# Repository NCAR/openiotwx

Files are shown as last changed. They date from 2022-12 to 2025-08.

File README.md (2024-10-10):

# openIoTwx

Repo hosting the openIoTwx project by NCAR.

This website is currently a work in progress and is live here:

* [https://ncar.github.io/openiotwx](https://ncar.github.io/openiotwx)

If you are looking for the overarching openIoTwx Github repository (aka "openIoTwx Hub"), please go here:

* openIoTwx Hub repository: [https://github.com/ncar/openiotwx-hub](https://github.com/ncar/openiotwx-hub)

# For Developers 

We welcome contributions, so if you wish to contribute to this project please understand how to build it first.

The main development site uses [Material for MkDocs](https://squidfunk.github.io/mkdocs-material/).  You can [learn how to install it](https://squidfunk.github.io/mkdocs-material/getting-started/) and then you will be able to begin contributing.

The best way to work on this is to:

* fork the repo
* make a branch to work on revisions
* test locally using `mkdocs serve` (you will need to install mkdocs according to the documentation) 
* submit a Pull Request

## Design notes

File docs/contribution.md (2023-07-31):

# Contributing to this Project

We welcome any and all contributions. We'd love not only to see pictures of your builds and the data
that you produce (if you're willing to share), but also support for new sensors, new 3d designs for 
parts, and any feedback you have.

This [google form](https://forms.gle/mJmh5QLR8TvUpvbg8) is the best way to contribute non-code items. 

If you want to look further into this project, visit our various github repositories.

* For general issues and contributions go [here](https://github.com/NCAR/openiotwx-hub)
* For print issues and contribution go [here](https://github.com/NCAR/openiotwx-stl)
* For suggestions about this site go [here](https://github.com/NCAR/openiotwx)
* For issues and contributions to the flash code go [here](https://github.com/NCAR/esp32-atomlite-arduino-base)
* For issues and contributions to the library code go [here](https://github.com/NCAR/esp32-atomlite-arduino-iotwx)

Pieces we would love for you to contribute:

* A housing and sensor system for measuring atmospheric pollutants
* A low cost and low complexity method for getting anemometry
* Water quality / PFAS sensor integration

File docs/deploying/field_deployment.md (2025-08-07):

Properly situating a weather station in the field requires careful consideration for accurate data collection. When selecting a location, keep in mind a few important factors. 

* Place the weather station away from obstacles like tall trees or buildings that can disrupt airflow and affect wind measurements.
* Avoid areas with artificial heat sources such as asphalt or concrete, as they can cause higher temperature readings. 
* Also, make sure to position the station on stable ground to prevent measurement errors and ensure equipment stability.
* Mount the station at a suitable height, typically 1.5 to 2 meters above the ground, for reliable data.
* For LoRA Gateway Deployment, mount gateways at structural or geographic high point to maximize line of sight distance (i.e. roof, attic window, hilltop)
* For LoRA deployments, review antenna specifications for orientation to maximize signal. 

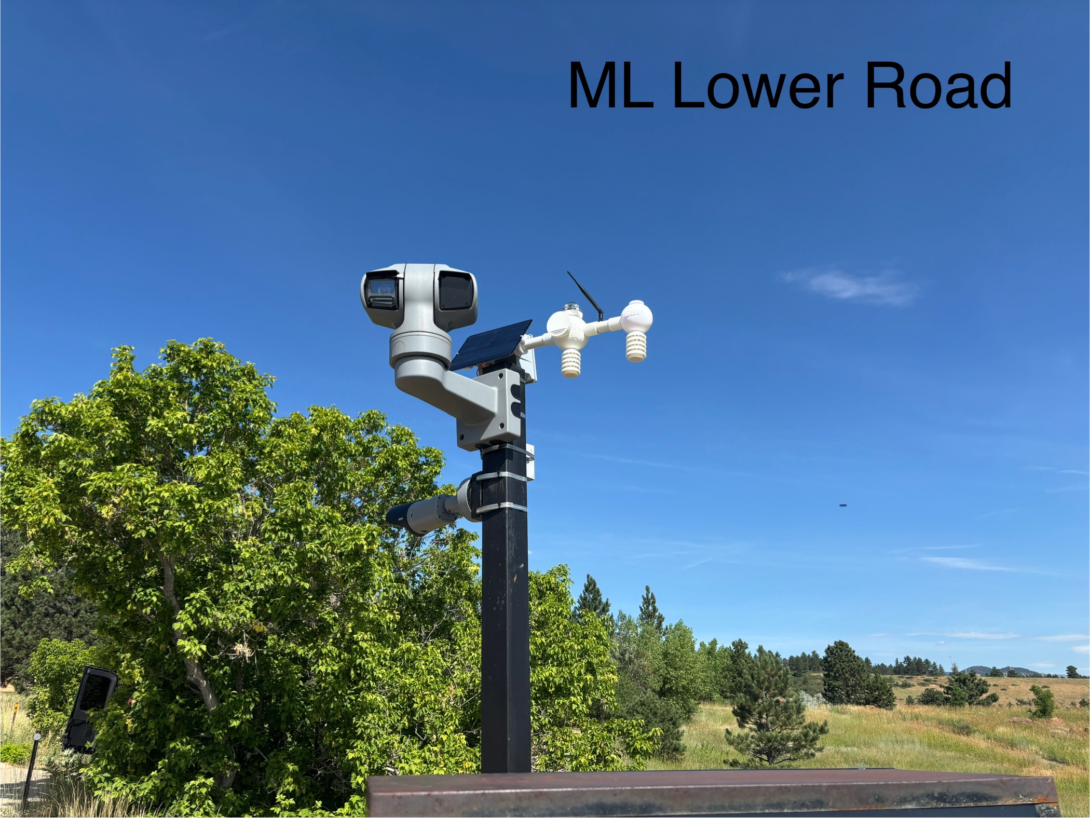
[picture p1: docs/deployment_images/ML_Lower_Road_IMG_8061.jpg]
Deployment ML Lower Road

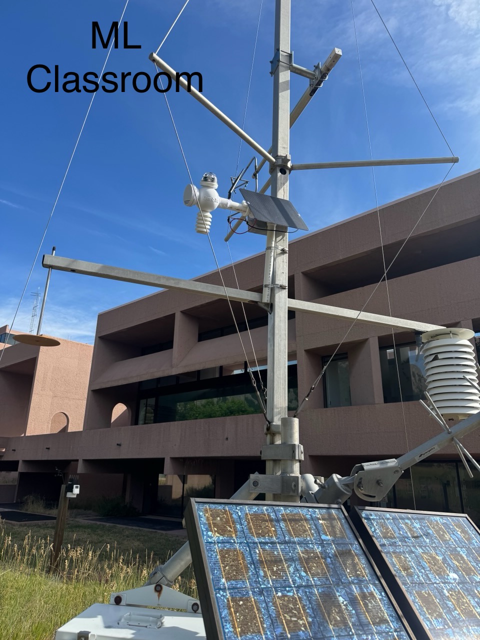
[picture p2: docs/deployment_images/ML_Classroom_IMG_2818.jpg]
Deployment ML Classroom

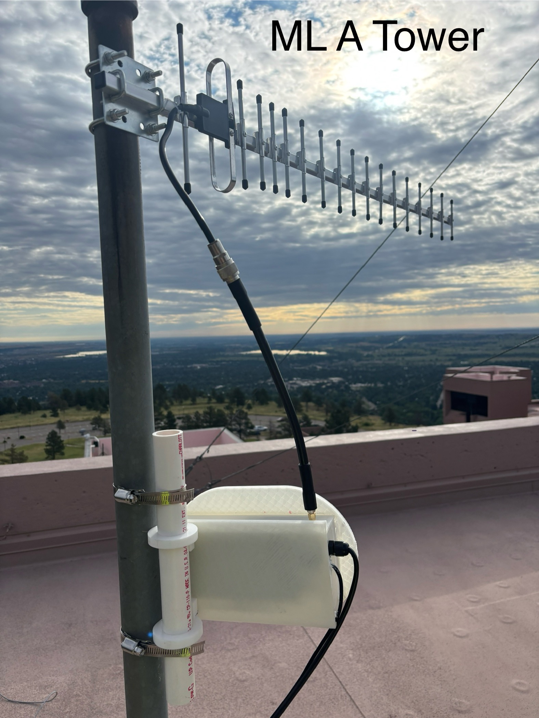
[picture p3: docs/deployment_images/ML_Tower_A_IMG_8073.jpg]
Deployment ML Tower A1 Gateway

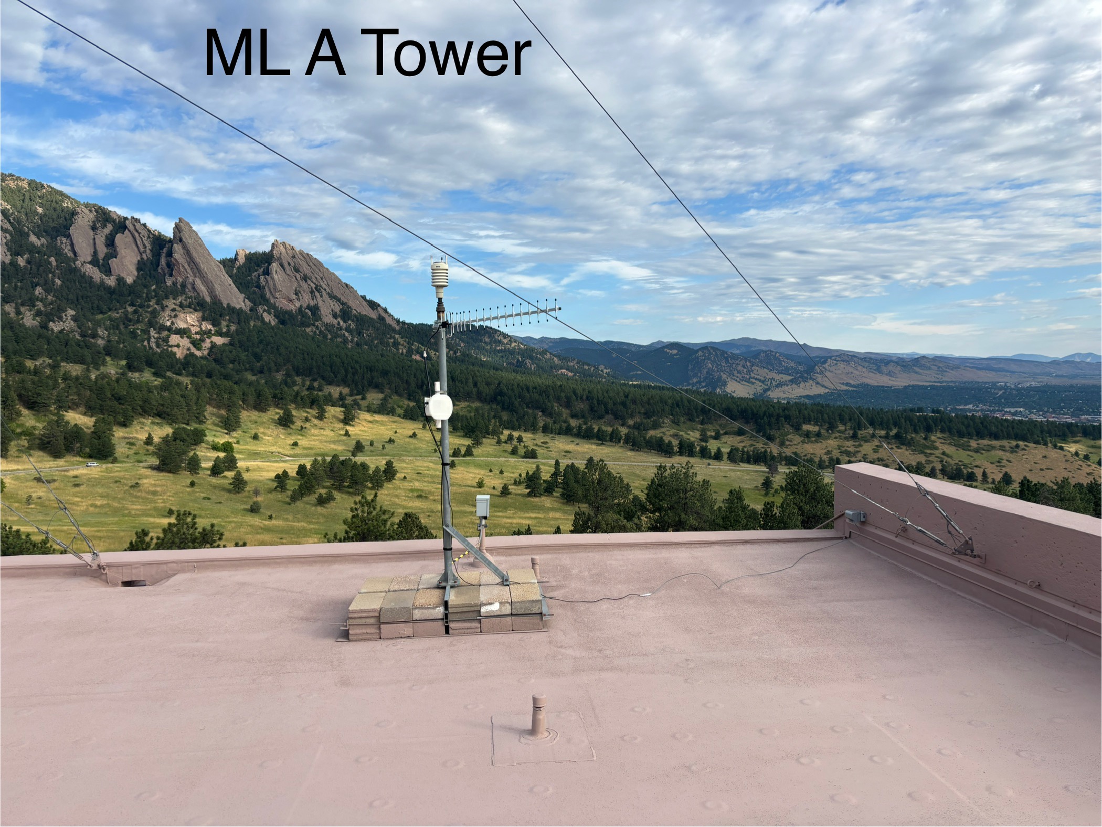
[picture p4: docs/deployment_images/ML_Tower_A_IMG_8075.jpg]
Deployment ML Tower A2 Gateway

Deployment ML Tower B Gateway
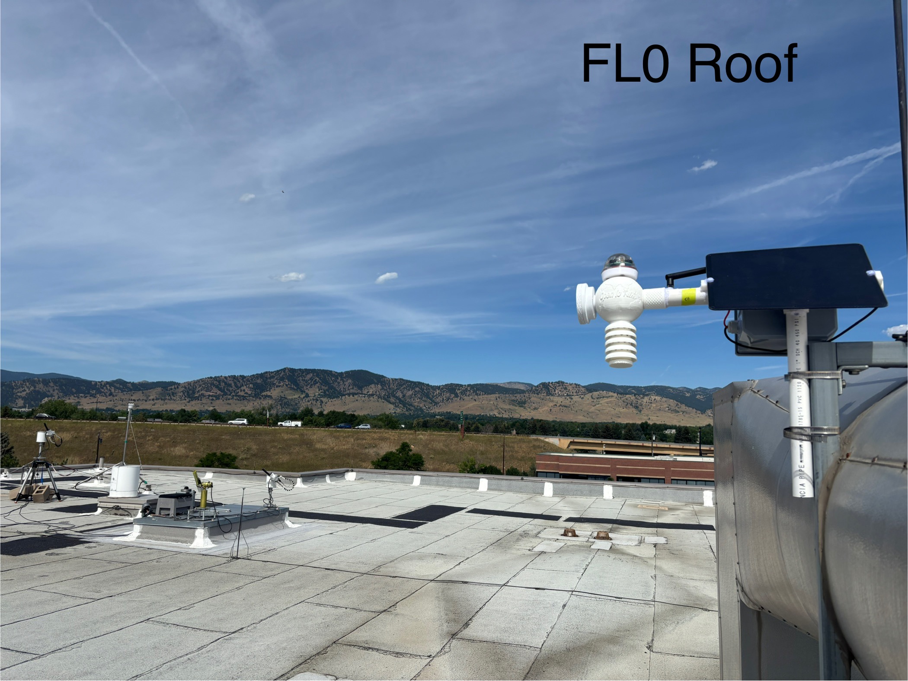
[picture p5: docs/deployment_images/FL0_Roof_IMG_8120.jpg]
Deployment FL Roof Gateway

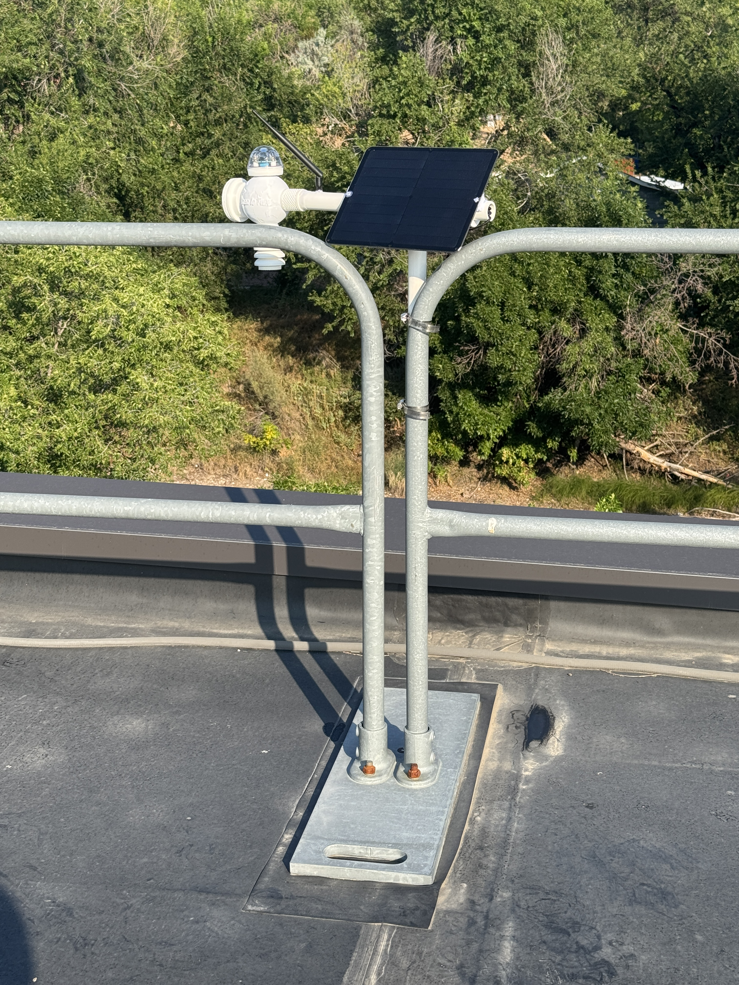
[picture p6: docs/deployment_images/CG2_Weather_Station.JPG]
Deployment CG2 Station

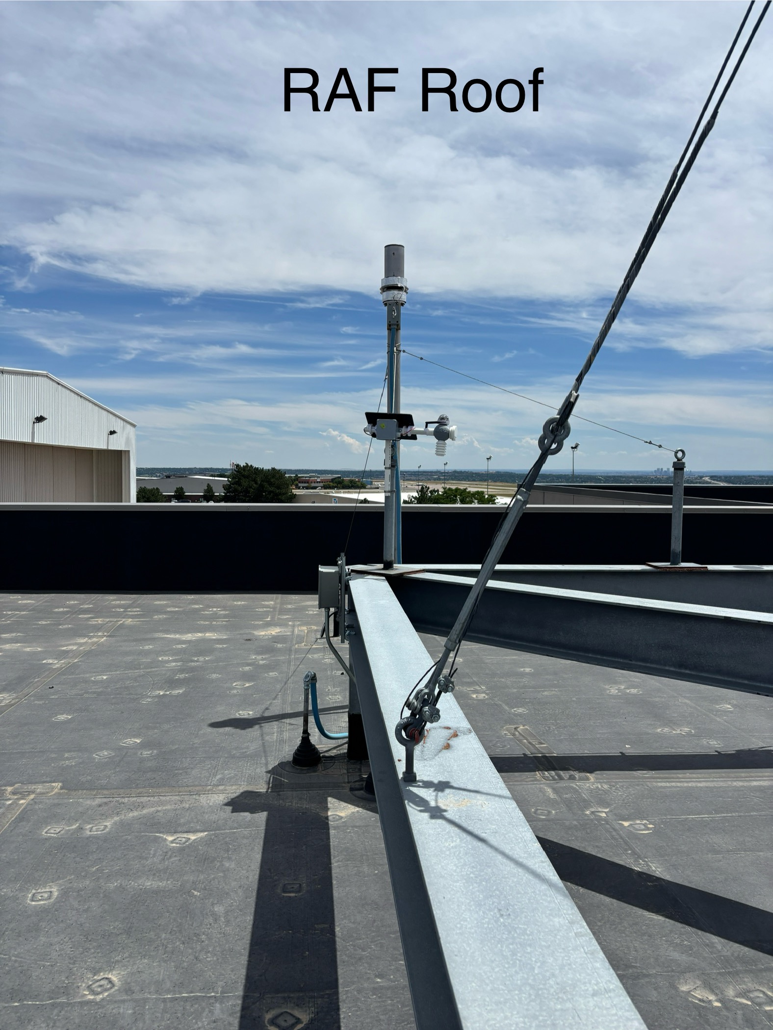
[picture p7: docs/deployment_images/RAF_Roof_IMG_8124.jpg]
Deployment RAF Station

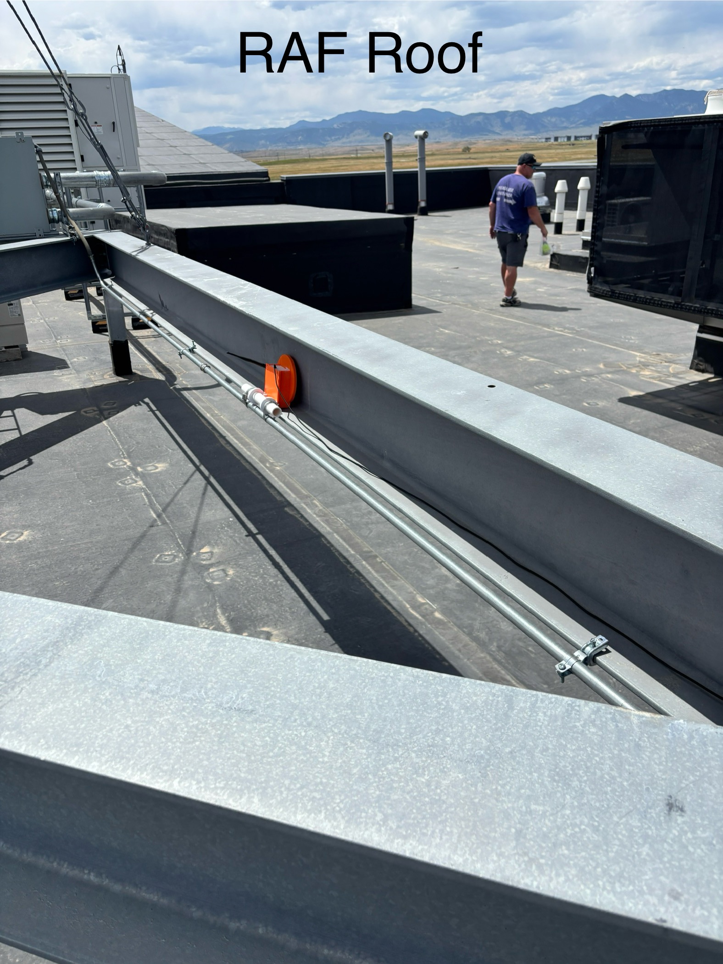
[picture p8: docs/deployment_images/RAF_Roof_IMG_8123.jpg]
Deployment RAF Roof Gateway

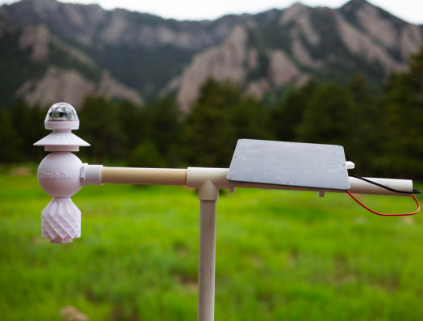
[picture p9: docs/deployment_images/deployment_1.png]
Deployment Example 1

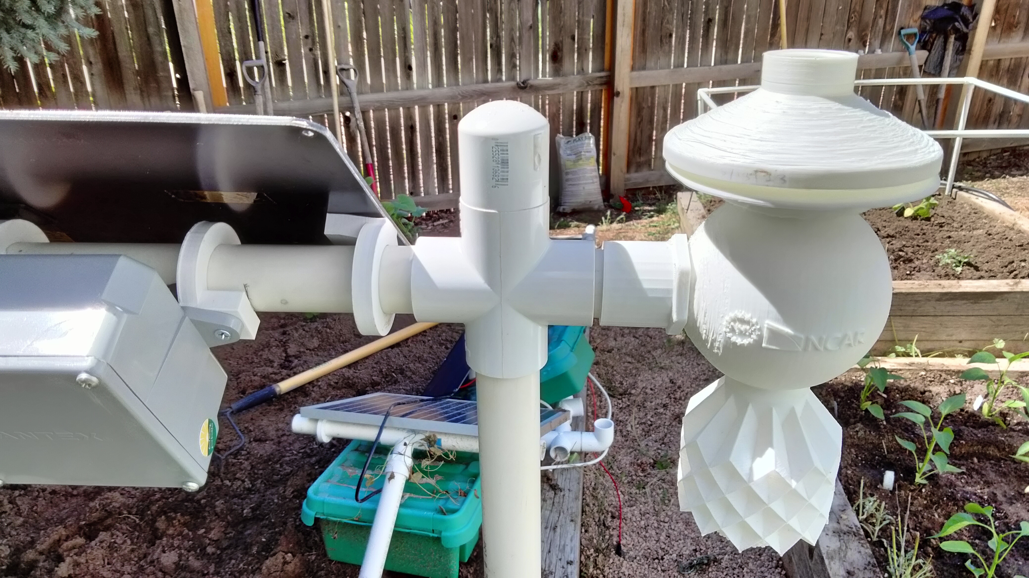
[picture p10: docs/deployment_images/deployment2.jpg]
Deployment Example 2


<!-- jfslhohshofsd -->

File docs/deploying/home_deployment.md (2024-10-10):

When deploying a weather station at a home, school, or in an otherwise developed area, there are a few important considerations to keep in mind. 

* Choose a location that is free from immediate obstructions such as nearby trees or tall structures that could affect other weather measurements. 
* Mount the station at a suitable height, typically 1.5 to 2 meters above the ground, for reliable data.
* Ensure that the station is not in direct contact with the building or any heat-emitting sources that could impact temperature readings.
* It is recommended to position the weather station in an area that receives adequate sunlight and is representative of the general microclimate of your surroundings. Avoid placing the station in shaded areas or near reflective surfaces that could distort solar radiation measurements. 
* Additionally, make sure the station is securely mounted, taking into account factors like stability and ease of access for maintenance.
* Regular checks and comparisons with nearby official weather sources can help ensure the accuracy of the collected data.

Deployment Example 1

Deployment Example 2

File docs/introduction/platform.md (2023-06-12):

# Platform

openIoTwx is an open source community committed to increasing access to weather
observation hardware, software, and data. This is achieved through our portable, 
modular, and affordable platform. openIoTwx can be installed with up to 7 
sensors or "nodes." These nodes include, but are not limited to: temperature, relative 
humidity, pressure, volatile organic compounds (VOCs), digital rain sensors, sky 
cameras, and sonic anemometers (Devices that measure wind speed). The platform is 
small enough to mount anywhere using low cost commercial off-the-shelf materials and 
3D printed parts.

Any of these nodes can be attached to the body using universal one inch screw-in 
connectors. This approach allows for any 1" PVC pipe or other threaded connector to be 
used as a base for the station. This specification was chosen due to how commonly 
available it is to find components that fit. The body of the station has threaded 
connectors. Depending on the housing used, there are between three and five ports. 

Users are provided with a starter set of screw in adaptors for an initial 
set of sensors such as the RG15 digital rain sensor, 
air quality monitor, and radiation shields. We also provide screw-in connectors with a 
cap so that users can cap off connectors not in use and deploy. This prevents water and 
dust from getting into the electronics. Should a user want to attach a new sensor, they 
can modify the 3D design files (provided in the print section) for whatever their 
needs demand.

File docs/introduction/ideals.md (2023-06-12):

# Ideals
The "Internet of Things" (IoT) revolution is about the world of sensors,
software, and electronics. It allows for ubiquitous, low-cost, and high quality
measurements of many things, including our Earth system. Due to low
cost-barriers, these sensing systems are now broadly accessible to many
communities. We hope that openIoTwx can continue piquing new interest in measurements and data relating to the all
aspects of our environment around us. We advise all members of our community to
review and regularly reflect on the core ideals outlined here.

The goals and core ideals of the openIoTwx project is _to advance low cost IoT
based geoscience observational projects_ via four objectives that align with and
build upon the National Science Foundation's (NSF) investments in the EarthCube
Community, ACCESS/Jetstream, 3D printed weather stations (aka "openIoTWx") and
future needs:

(1) create an open, diverse, community-driven and community-managed ecosystem to
empower fledgling open source sensor projects for open environmental sensing.

(2) implement an efficient, scalable, and simplified open project submission and
contribution framework to provide equitable access across disciplines,
stakeholders, institutions, and demographics to grow a community managed suite
of open source IoT observational sensor network projects;

(3) building upon NSF’s Cloud-Hosted Real-time Data Services for the Geosciences
(CHORDS) and other components, develop a robust, decentralized, and flexible
community software contribution platform to bring the open source project
development and design cycle into a new collaborative and cooperative
environment to spur sustainable community growth; 

(4) provide cyber-infrastructure (CI) integration through the ACCESS innovation
pilot program to manage dataflows, analysis, address artificial intelligence and
machine learning of earth science time series streams, creating open source
community deployments that are accessible while recognizing and honoring data
sovereignty aspects of our communities.

## Opensource is at our core
Our community holds the ideals of open source technology very close (for more
see [https://opensource.org](https://opensource.org)). openIoTwx broadly
promotes the MIT open source license and is accessible to all for non-commercial
use. Open source is an important ideal for our community because it facilitates
community engagement, provides transparency that builds trust and encourages
sharing of data, code, hardware  community earth system science data and ideas.

## FAIR and CARE 
We are committed to the Findability, Accessibility, Interoperability, and Reuse
(FAIR) of all digital assets (see
[https://www.go-fair.org/fair-principles/](https://www.go-fair.org/fair-principles/))
needed to design, modify, build, deploy, analyze and archive the openIoTwx
station. The FAIR principle as defined by GO-FAIR.ORG is a core value that will
help make this community open and accessible to all.

We balance adherence to FAIR principles with CARE
([https://www.gida-global.org/care](https://www.gida-global.org/care)) or
Collective Benefit, Authority to Control, Responsibility, and Ethics. This is
important for our community members from tribal communities and
other marginalized groups. Please review the CARE principle
summary as linked above.

## FPIC 
Free Prior and Informed Consent (FPIC) is a specific right that pertains to
indigenous peoples and is recognised in the United Nations Declaration on the
Rights of Indigenous Peoples (UNDRIP). It allows them to give or withhold
consent to a project that may affect them or their territories. This is another
core ideal of the openIoTwx community and should also be reviewed. (for
more see [https://www.fao.org/indigenous-peoples/our-pillars/fpic/en/](https://www.fao.org/indigenous-peoples/our-pillars/fpic/en/))

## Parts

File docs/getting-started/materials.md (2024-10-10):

# Materials

Within this page you can see all of the required materials for building the base unit, as 
well as the materials for adding sensors and other 'accessory' nodes. If you already have some of 
these pieces, for example, a 3d printer, you don't need to factor that into the cost. We have 
included every sensor that we currently support for the station within this list. If you have other 
sensors you wish to include, we would be thrilled for you to modify the codebase and send us a pull request 
or send a comment to us via our [Contribution](../contribution.md) portal.

The station can be powered and connected via ethernet or independently. The materials needed will be different depending on which configuration you use. Pay attention to the headings on the table below to make sure the materials you purchase are appropriate for the configuration that meets your needs. If you need more information to decide which configuration is best for your specific circumstance, go to the [Determining power & internet needs](../getting-started/connection.md) page.

## Printing Gear

Only one roll of filament is required.

|Area|Component|Price Per Unit|Number of Units|Total Price|Source|
|---|---|---|---|---|---|
|Printing|Ender 3 S1|$349.00|1|$349.00|[(Amazon)](https://www.amazon.com/Creality-S1-Extruder-Mainboard-8-6X8-6X10-6in/dp/B07DYL9B2S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)|
|Printing|PLA+ Filament|$20.99|1|$20.99|[(Amazon)](https://www.amazon.com/Printer-Filament-SUNLU-Dimensional-Accuracy/dp/B08CVG79JM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)|
|Printing|Tough PLA|$24.99|1|$24.99|[(Amazon)](https://www.amazon.com/Inland-Tough-Printer-Filament-1-75/dp/B09P497QP7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)|

## Base Station with Independent Comms and Power

|Area|Component|Price Per Unit|Number of Units|Total Price|Source|
|---|---|---|---|---|---|
|Microcontroller|M5 atomlite|$7.50|1|$7.50|[(M5)](https://shop.m5stack.com/products/atom-lite-esp32-development-kit)|
|Cables|qwiic to grove cable|$1.60|1|$1.60|[(sparkfun)](https://www.sparkfun.com/products/15109)|
|Cables|qwiic adapter|$1.60|1|$1.60|[(sparkfun)](https://www.sparkfun.com/products/14495)|
|Cables|qwiic multiport|$2.10|1|$2.10|[(sparkfun)](https://www.sparkfun.com/products/18012)|
|Cables|qwiic cable 500mm|$2.10|1|$2.10|[(sparkfun)](https://www.sparkfun.com/products/17257)|
|Cables|qwiic cable 200mm|$1.60|2|$3.20|[(sparkfun)](https://www.sparkfun.com/products/17258)|
|Cables|qwiic cable 100mm|$1.60|1|$1.60|[(sparkfun)](https://www.sparkfun.com/products/17259)|
|Cables|Grove to GPIO|$3.50|1|$3.50|[(Seeed studio)](https://www.seeedstudio.com/Grove-4-pin-Female-Jumper-to-Grove-4-pin-Conversion-Cable-5-PCs-per-PAck.html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)|
|Cables|Qwiic to GPIO|$1.50|1|$1.50|[(sparkfun)](https://www.sparkfun.com/products/14425)|
|Cables|usbC=>usbA adapter (2pk)|$7.99|1|$7.99|[(amazon)](https://www.amazon.com/Adapter%EF%BC%8CUSB-Converter-Synchronization-Charging-Computers/dp/B08P57T56M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)|
|Cables|usbC=>usbA 10ft cable (5pk)|$13.59|1|$13.59|[(amazon)](https://www.amazon.com/s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)|
|Sensors|adafruit bme680|$18.95|1|$18.95|[(mouser)](https://www.mouser.com/ProductDetail/Adafruit/3660?qs=W0yvOO0ixfFypXCClAyRMg%3D%3D)|
|Sensors|RG-15 Rain Gauge|$99.00|1|$99.00|[(mouser)](https://www.mouser.com/ProductDetail/Seeed-Studio/114992321?qs=W%2FMpXkg%252BdQ4dWj25F6J2Gg%3D%3D)|
|Sensors|adafruit pm2.5|$44.95|1|$44.95|[(adafruit)](https://www.adafruit.com/product/4632)|
|Sensors|adafruit ltr390|$4.95|1|$4.95|[(mouser)](https://www.mouser.com/ProductDetail/Adafruit/4831?qs=pBJMDPsKWf1zkcVjRyCEJQ%3D%3D)|
|Power|voltaic v75 (20mah)|$79.00|1|$79.00|[(voltaic)](https://voltaicsystems.com/v75/)|
|Power|voltaic 20w solar panel|$99.00|1|$99.00|[(voltaic)](https://voltaicsystems.com/20-watt-6-volt-solar-panel-etfe/)|
|Power|Junction Box|$15.93|1|$15.93|[Home Depot](https://www.homedepot.com/p/4-in-x-4-in-x-4-in-Junction-Box-R5133709/202043437)|
|Communications|KuWfi 4G Hotspot|$36.99|1|$36.99|[(Amazon)](https://www.amazon.com/KuWFi-Internet-Devices-Portable-Hotspot/dp/B08NX14VQZ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)|
|Communications|Redpocket 1 yr SIM (TMOBILE ONLY)|$30.00|1|$30.00|[(ebay)](https://www.ebay.com/itm/133196831828?hash=item1f03265c54:g:gXsAAOSww2Zfu-Xf)|

## Base Station using PoE

|Area|Component|Price Per Unit|Number of Units|Total Price|Source|
|---|---|---|---|---|---|
|PoE|PoE Converter|$39.90|1|$39.90|[(M5)](https://shop.m5stack.com/products/atom-poe-kit-with-w5500-hy601742e)|
|Cables|qwiic to grove cable|$1.60|1|$1.60|[(sparkfun)](https://www.sparkfun.com/products/15109)|
|Cables|qwiic adapter|$1.60|1|$1.60|[(sparkfun)](https://www.sparkfun.com/products/14495)|
|Cables|qwiic multiport|$2.10|1|$2.10|[(sparkfun)](https://www.sparkfun.com/products/18012)|
|Cables|qwiic cable 500mm|$2.10|1|$2.10|[(sparkfun)](https://www.sparkfun.com/products/17257)|
|Cables|qwiic cable 200mm|$1.60|2|$3.20|[(sparkfun)](https://www.sparkfun.com/products/17258)|
|Cables|qwiic cable 100mm|$1.60|1|$1.60|[(sparkfun)](https://www.sparkfun.com/products/17259)|
|Cables|Grove to GPIO|$3.50|1|$3.50|[(Seeed studio)](https://www.seeedstudio.com/Grove-4-pin-Female-Jumper-to-Grove-4-pin-Conversion-Cable-5-PCs-per-PAck.html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)|
|Cables|Qwiic to GPIO|$1.50|1|$1.50|[(sparkfun)](https://www.sparkfun.com/products/14425)|
|Cables|usbC=>usbA adapter (2pk)|$7.99|1|$7.99|[(amazon)](https://www.amazon.com/Adapter%EF%BC%8CUSB-Converter-Synchronization-Charging-Computers/dp/B08P57T56M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)|
|Cables|usbC=>usbA 10ft cable (5pk)|$13.59|1|$13.59|[(amazon)](https://www.amazon.com/s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)|
|Sensors|adafruit bme680|$18.95|1|$18.95|[(mouser)](https://www.mouser.com/ProductDetail/Adafruit/3660?qs=W0yvOO0ixfFypXCClAyRMg%3D%3D)|
|Sensors|RG-15 Rain Gauge|$99.00|1|$99.00|[(mouser)](https://www.mouser.com/ProductDetail/Seeed-Studio/114992321?qs=W%2FMpXkg%252BdQ4dWj25F6J2Gg%3D%3D)|
|Sensors|adafruit pm2.5|$44.95|1|$44.95|[(adafruit)](https://www.adafruit.com/product/4632)|
|Sensors|adafruit ltr390|$4.95|1|$4.95|[(mouser)](https://www.mouser.com/ProductDetail/Adafruit/4831?qs=pBJMDPsKWf1zkcVjRyCEJQ%3D%3D)|

## Optional Materials

A note on optional materials. If you are hosting in a sunny place and running your station with a relatively low
power configuration, you can use a smaller solar panel and battery (below). 
Additionally, for better print quality, a PEI plate can be quite nice, although not necessary by any means.

|Area|Component|Price Per Unit|Number of Units|Total Price|Source|
|---|---|---|---|---|---|
|Power|voltaic 10w solar panel|$65.00|1|$65.00|[(voltaic)](https://voltaicsystems.com/10-watt-panel-etfe/)|
|Power|voltaic v25 (6000mah)|$39.00|1|$39.00|[(voltaic)](https://voltaicsystems.com/v25/)|
| Printing | PEI Magnetic Flexible Heated Bed Plate | $25.99 | 1 | $25.99 | [Amazon](https://www.amazon.com/Magnetic-Flexible-Heated-235x235mm-Ender/dp/B09F6Q4CYM?th=1)|

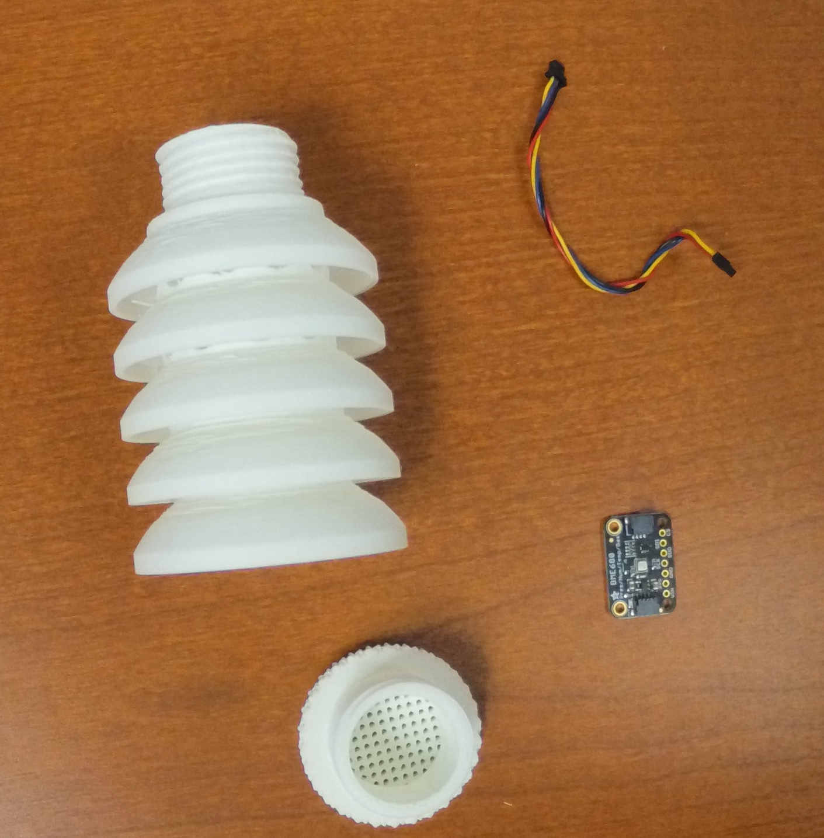
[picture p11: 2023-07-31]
docs/build_img/radiation_parts.jpg

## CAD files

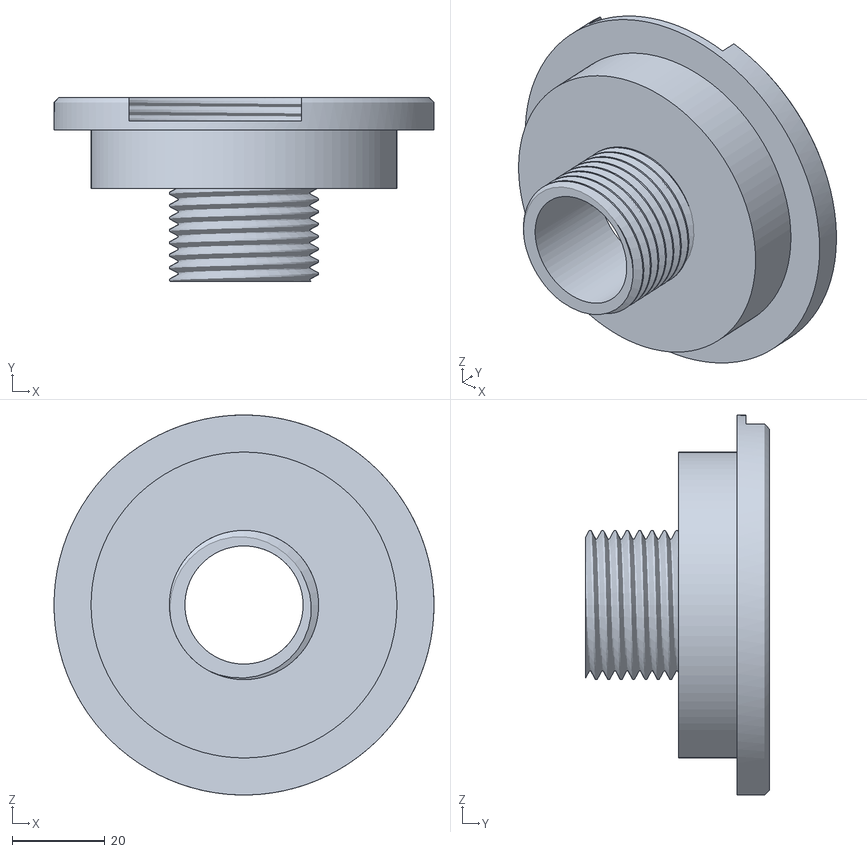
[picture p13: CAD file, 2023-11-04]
docs/print_files/air_quality/AQ_Housing_Vented_Male.stl
82.0 x 39.6 x 82.0

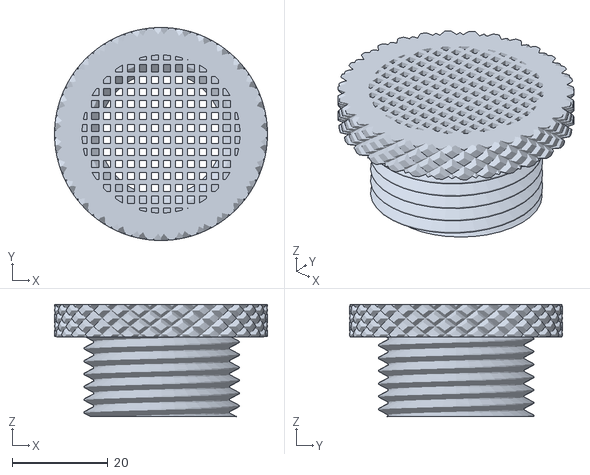
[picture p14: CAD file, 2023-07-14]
docs/print_files/caps/Cap_Vent.stl
44.5 x 44.5 x 23.4

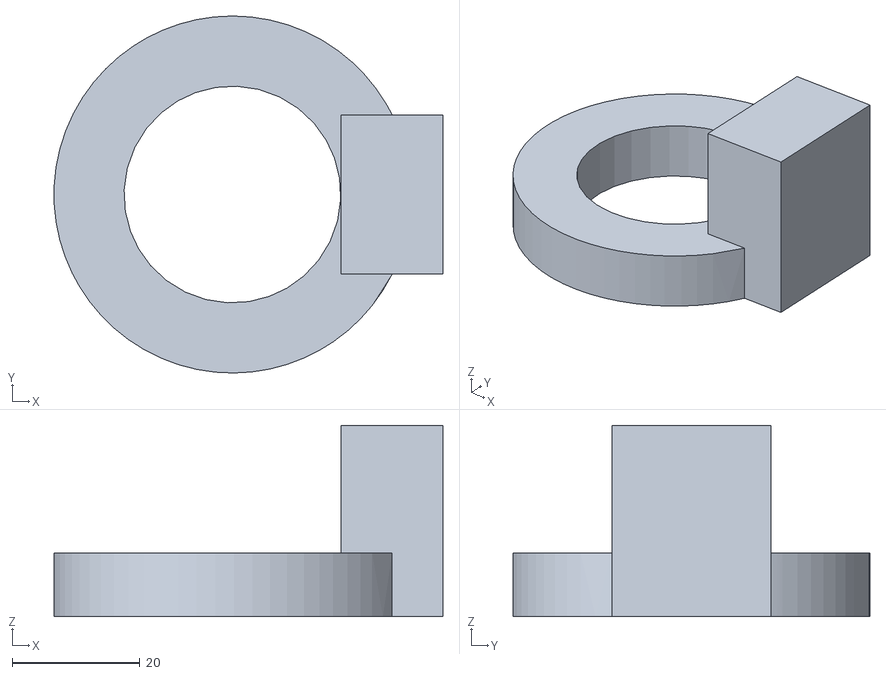
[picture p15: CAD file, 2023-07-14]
docs/print_files/fittings/PVC_16mm_clamp.stl
61.0 x 56.0 x 30.0

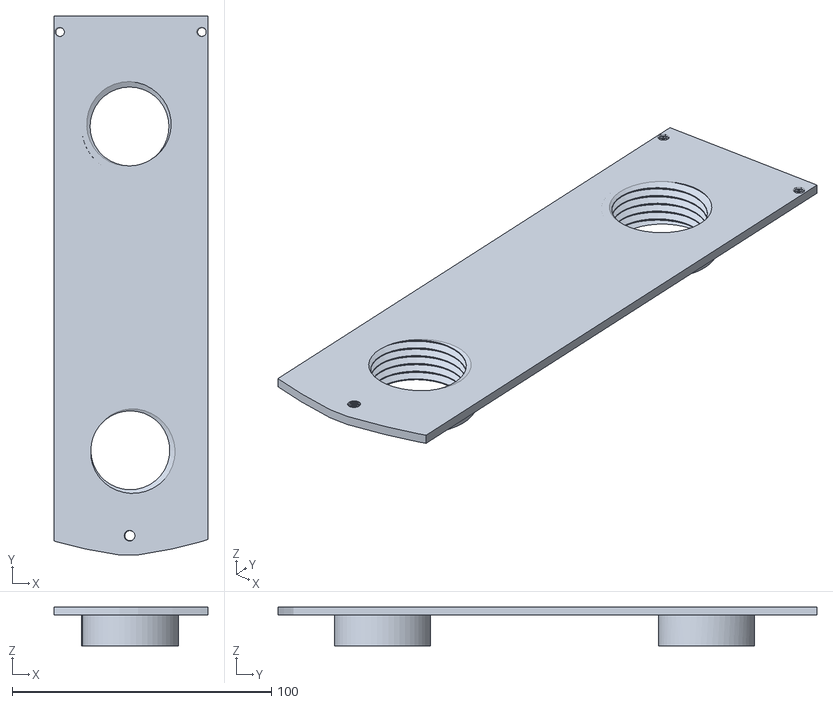
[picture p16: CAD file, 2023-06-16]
docs/print_files/large_housing/large_Lid.stl
59.3 x 207.8 x 15.0

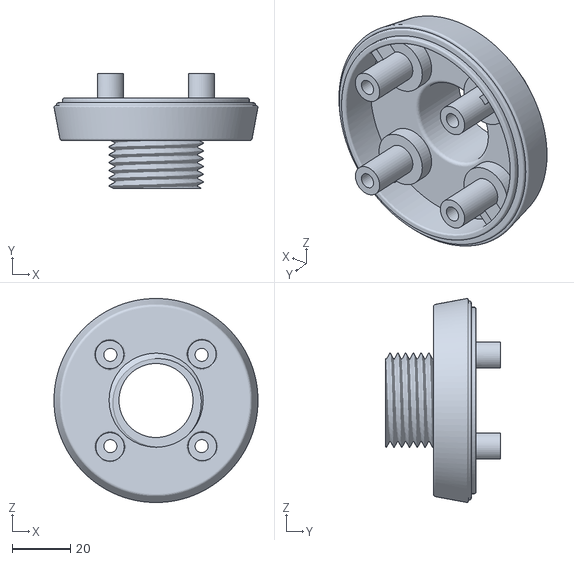
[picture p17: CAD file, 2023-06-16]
docs/print_files/rain_gauge/RG15_Housing.stl
70.3 x 39.5 x 70.3

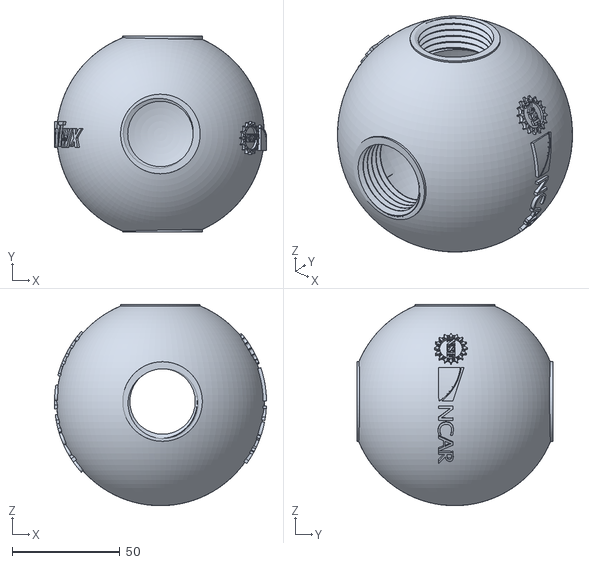
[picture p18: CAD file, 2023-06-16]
docs/print_files/sphere_housing/sphere_housing.stl
98.5 x 91.0 x 93.6

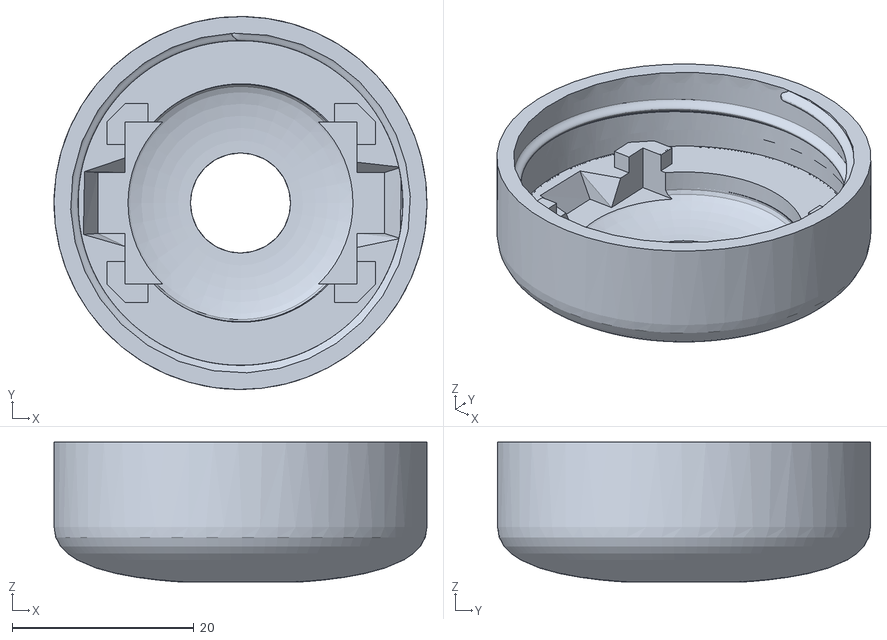
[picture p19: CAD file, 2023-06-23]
docs/print_files/uv/UV_Cap.stl
41.0 x 41.0 x 15.4

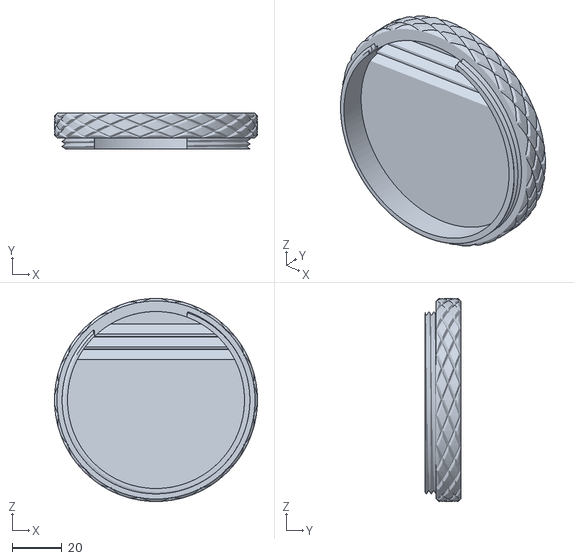
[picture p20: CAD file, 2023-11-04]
docs/print_files/air_quality/AQ_Lid_Half_Vented.stl
82.0 x 14.5 x 82.0

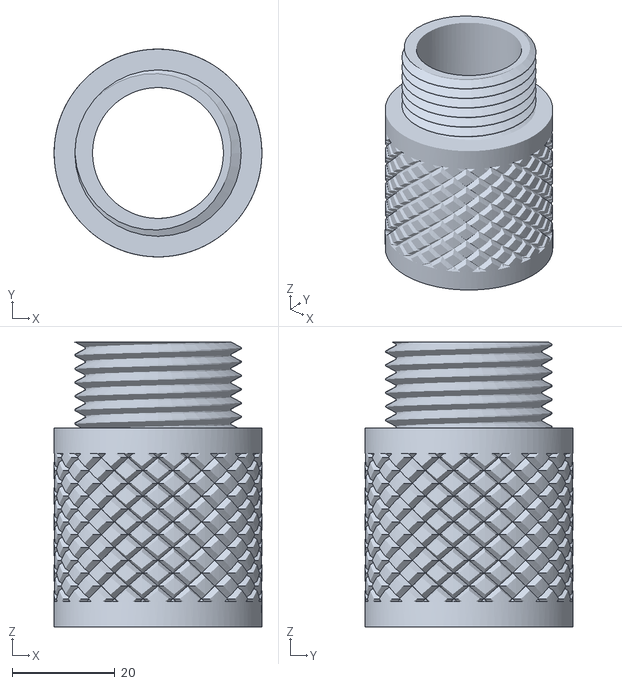
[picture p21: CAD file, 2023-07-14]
docs/print_files/caps/Adapter.stl
40.5 x 40.5 x 55.6

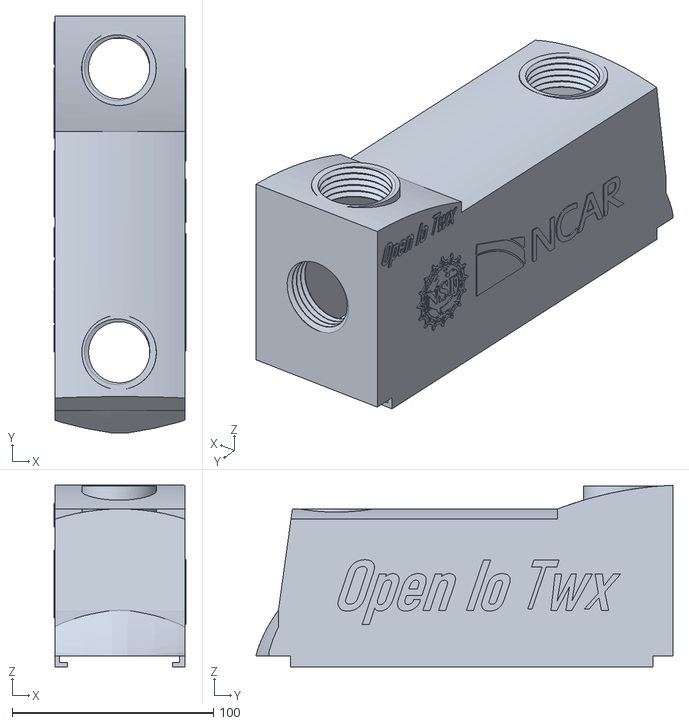
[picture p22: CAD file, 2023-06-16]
docs/print_files/large_housing/large_housing.stl
65.4 x 207.1 x 90.2

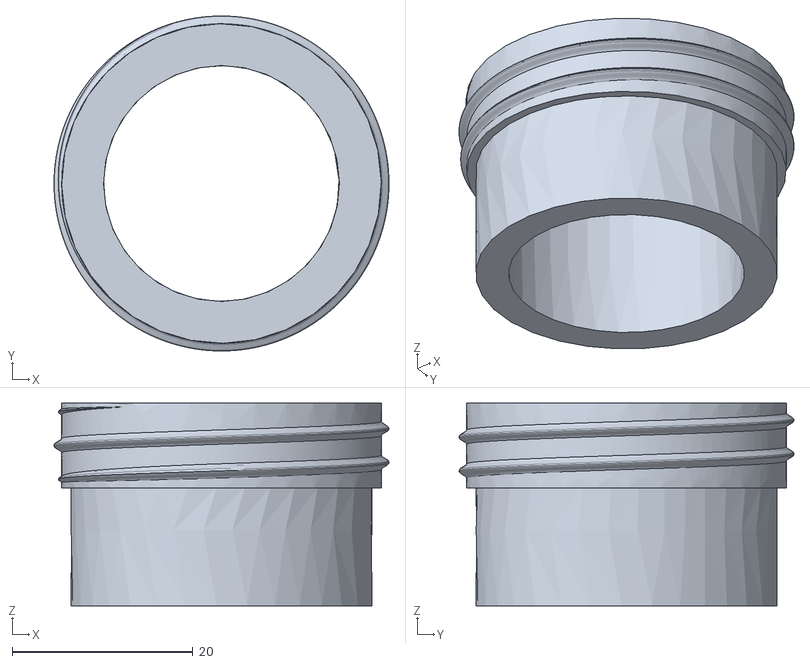
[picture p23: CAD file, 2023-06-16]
docs/print_files/uv/UV_tube.stl
37.1 x 37.1 x 22.4

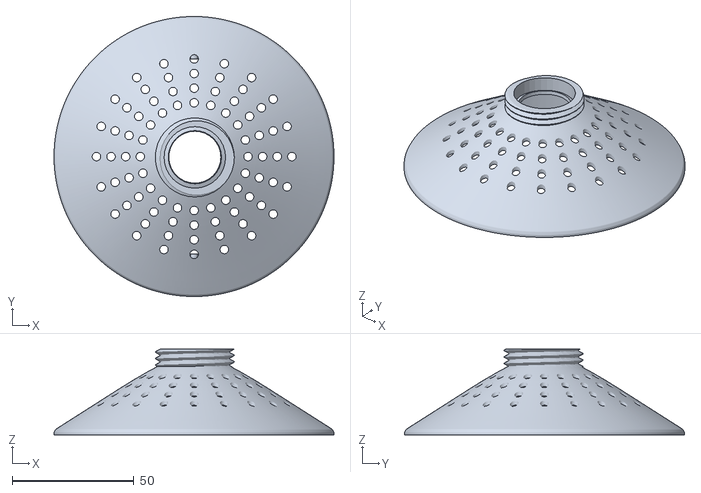
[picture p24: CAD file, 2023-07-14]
docs/print_files/air_quality/AQ_Lid_Lock.stl
114.9 x 114.9 x 35.2

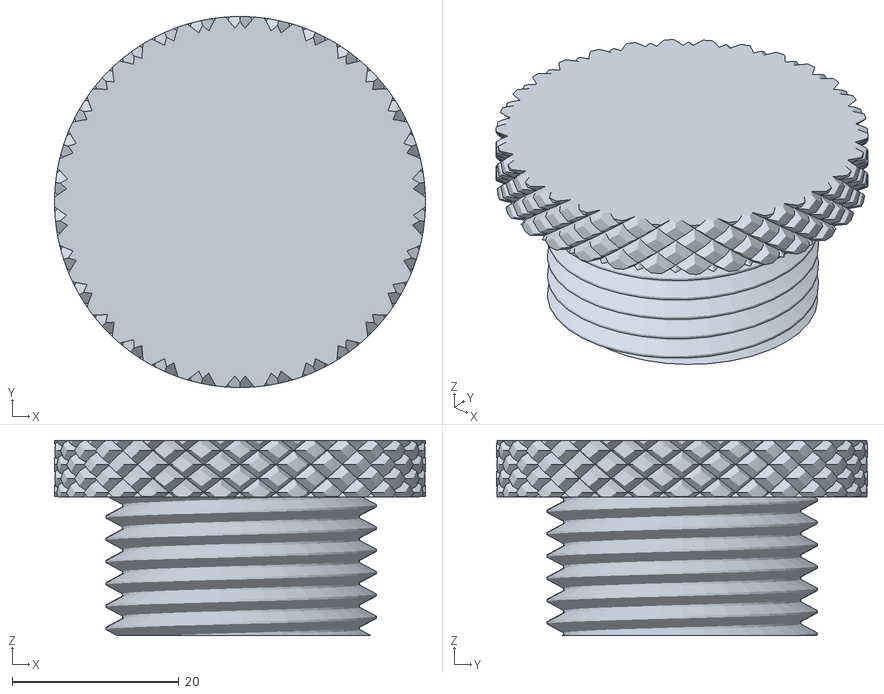
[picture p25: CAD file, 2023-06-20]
docs/print_files/caps/Cap_Closed.stl
44.5 x 44.5 x 23.4

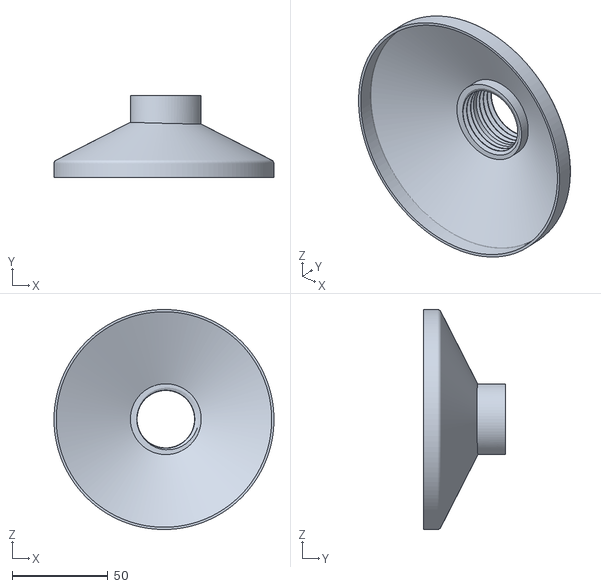
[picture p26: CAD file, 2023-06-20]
docs/print_files/air_quality/AQ_Cap.stl
115.0 x 43.0 x 115.0

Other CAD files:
docs/print_files/caps/Cap_Open.stl
docs/print_files/air_quality/AQ_Housing_Male.stl

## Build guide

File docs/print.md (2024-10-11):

# Printing out the station

Attached in this document are all of the .stl (3d printing files) for the various housing components.

While we didn't feel it made sense to share gcodes for the various printing operations, here are some thoughts for settings:

1. Stay fairly near manufacturers' suggestions for bed and nozzle temperatures unless you are a seasoned 3D printer.
2. Lower support densities and/or use tree supports to save material, limit post-processing, and increase print quality.
3. Print multiple parts at once. It saves time.
4. Print the cap and lid lock for air quality sideways, it'll increase quality significantly.
5. Print the orb housing with tree supports so that the top threading forms correctly.

## Base Unit

|Name|Image|STL File|Notes|
|---|---|---|---|
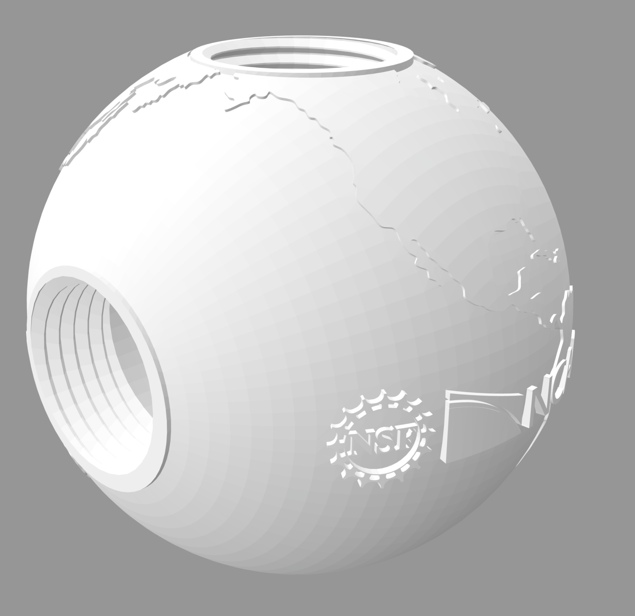
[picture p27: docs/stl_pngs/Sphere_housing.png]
Orb Housing
|Orb Housing||[Orb Housing STL File](./print_files/sphere_housing/sphere_housing.stl)|This is the base of the weather station, where the microcontroller and most wires will go. <br/><br/> You can also find the full suite of STL files which include 3.8" and 4.5" orbs here: [https://github.com/NCAR/openiotwx-stl/tree/main/housing](https://github.com/NCAR/openiotwx-stl/tree/main/housing). |

## Base Attachments

|Name|Image|STL File|Notes|
|---|---|---|---|
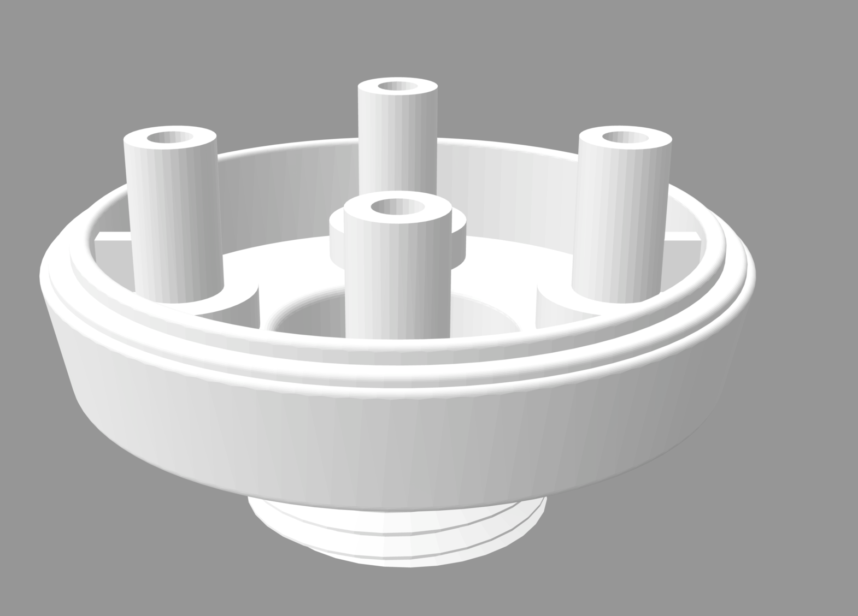
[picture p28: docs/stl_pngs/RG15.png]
RG15
|Rain Gauge||[Rain Gauge STL File](./print_files/rain_gauge/RG15_Housing.stl)|This will replace the manufacturers rain gauge base so the gauge can screw into the orb housing.|
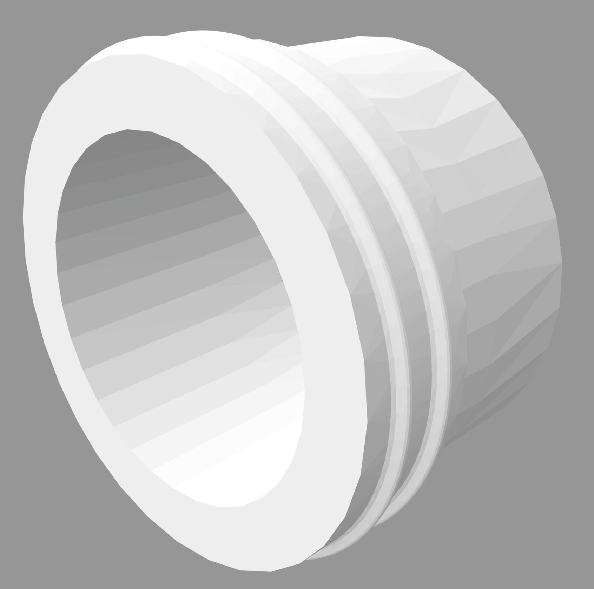
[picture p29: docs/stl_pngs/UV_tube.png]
|UV Tube||[UV tube STL File](./print_files/uv/UV_tube.stl)| This will screw into the UV Cap to hold the UV sensor in place and allow it to fit into PVC housing.|
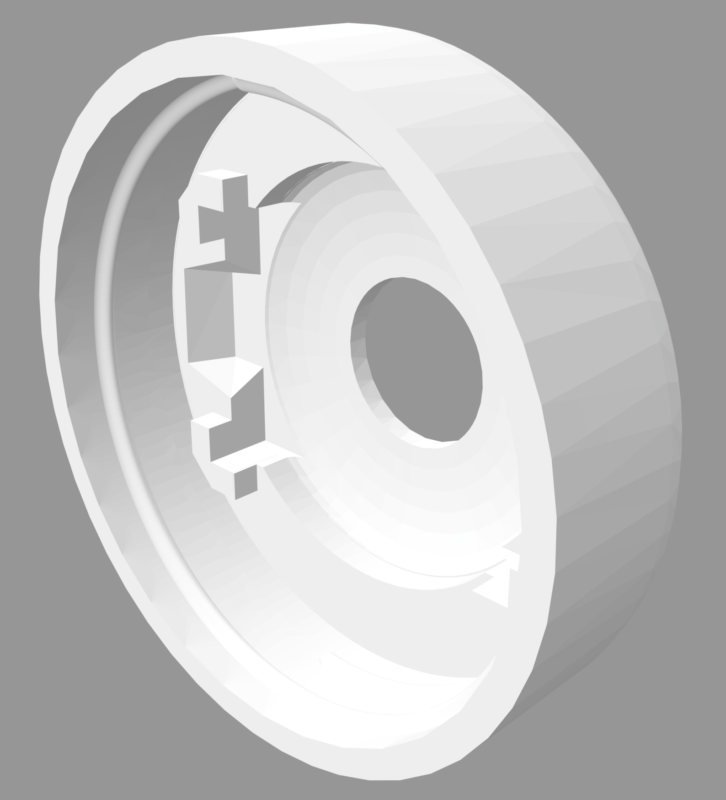
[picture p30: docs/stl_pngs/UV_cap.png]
|UV Cap||[UV Cap STL File](./print_files/uv/UV_Cap.stl)| The UV sensor will sit inside the fitted corners of this cap and be held in place by the UV tube.|
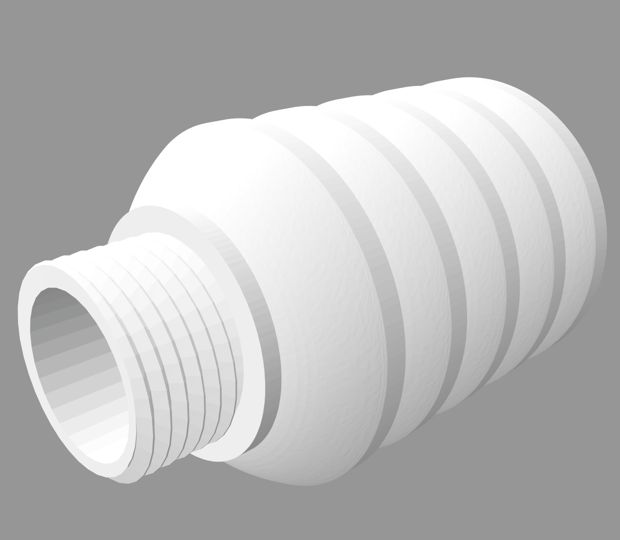
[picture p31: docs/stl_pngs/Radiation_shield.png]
Radiation
|Radiation Shield||[Radiation Shield STL File](./print_files/radiation_shield/Radiation_Shield.stl)|The bottom opening of this shield is threaded so another part can be screwed into it. In a simple station this would likely mean the vented cap (see key accessories).|
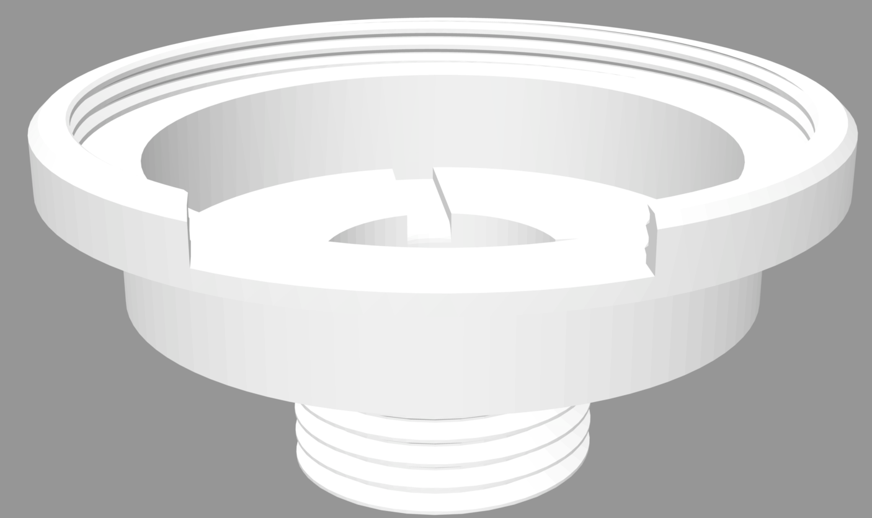
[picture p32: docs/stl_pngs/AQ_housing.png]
AQ Housing
|Air Quality Body||[Air quality lid lock STL File](./print_files/air_quality/AQ_Lid_Half_Vented.stl)|Be sure the gap on the rim of this part faces downward during assembly so water cannot get into the sensor.|
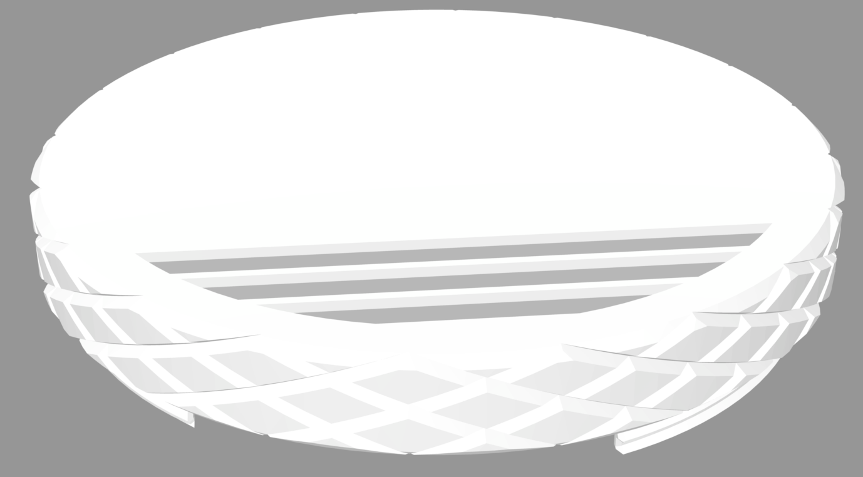
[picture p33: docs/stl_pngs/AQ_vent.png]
AQ lid lock
|Air Quality Cap||[Air quality lid lock STL File](./print_files/air_quality/AQ_Lid_Half_Vented.stl)| Be sure the vented openings face downwards during assembly so water cannot get into the sensor.|

## Key Accessories
|Name|Image|STL File|Notes|
|---|---|---|---|
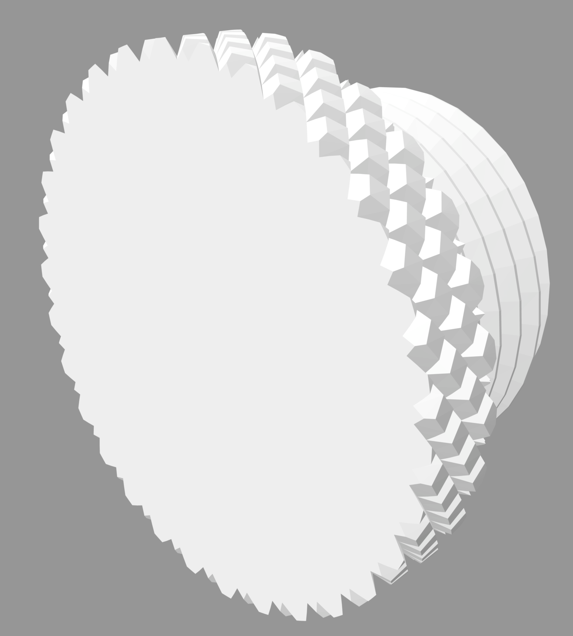
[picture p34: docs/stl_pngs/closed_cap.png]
closed
|Closed Cap||[Closed cap STL File](./print_files/caps/Cap_Closed.stl)|This can close off any unused openings in the orb housing.|
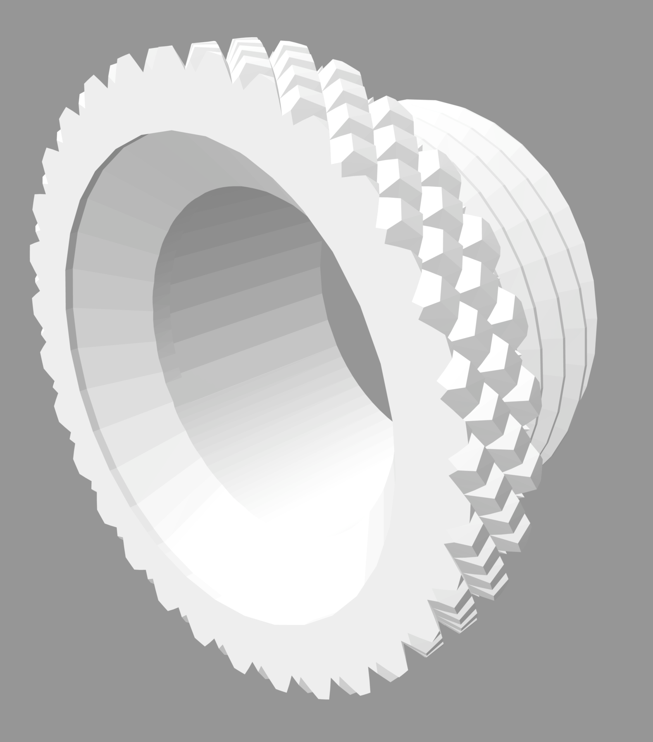
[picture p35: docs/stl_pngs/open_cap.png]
open
|Open Cap||[Open cap STL File](./print_files/caps/Cap_Open.stl)| This allows passage of external wiring into the orb housing.|
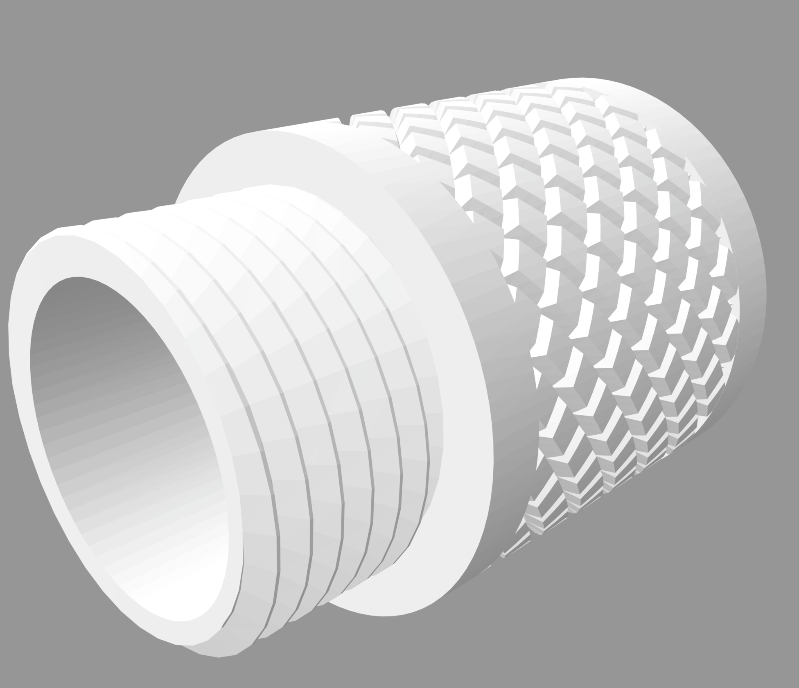
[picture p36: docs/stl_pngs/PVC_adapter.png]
PVC Adapter
|PVC Adapter||[Threading to PVC adapter STL File](./print_files/caps/Adapter.stl)|This allows the orb housing to be attached to PVC pipe, which can help with running wires and field set up.|
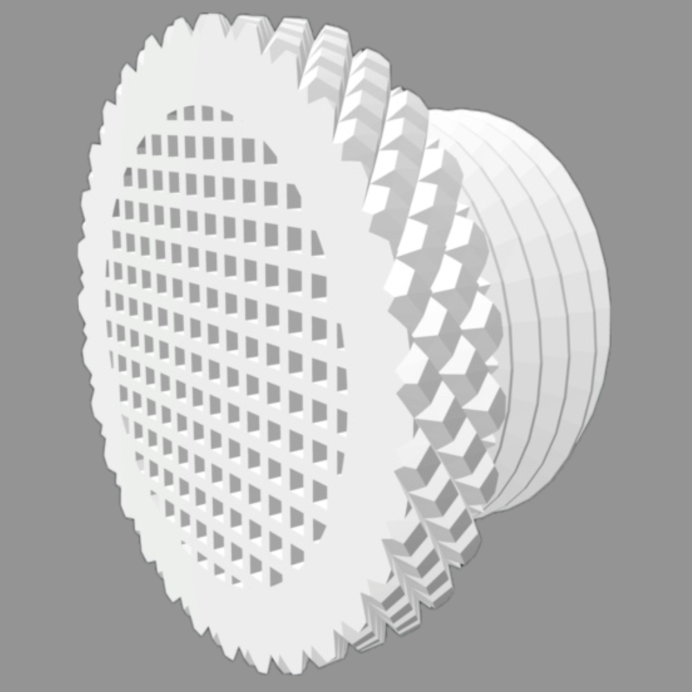
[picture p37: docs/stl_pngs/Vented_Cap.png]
Vented Cap
|Vented Cap||[Vented Cap STL File](./print_files/caps/Cap_Vent.stl)|This is helpful for anywhere that may overheat, especially the opening at the bottom of the radiation shield.|

Note: Not all key accessories may be necessary for your weather station and you may need more than one of some accessories. This will depend of your specific weather station design.

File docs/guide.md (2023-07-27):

# How to follow these instructions

We, the Open IoTwx team, have worked to make the documentation for making your own station as
friendly as possible. That being said, this project does require some care and effort, so we thought 
we'd include something of a step-by-step for you to refer to in case you find yourself a little lost.

1. Give this documentation a quick read-through. See what this project entails and what you need to
learn or already know.
2. Make a plan. Figure out what 3d printer you'll buy/use, which sensors you want to attach, etc.
3. Download all the needed [software](getting-started/software.md).
It's always good to make sure your computer can do what you need. 
4. Get your [materials](getting-started/materials.md). 
Buy the items you need so you can streamline the process when parts arrive.
5. Start [printing](print.md). This step takes the most time so it's good to get the printer running early.
6. [Flash](installation/core_install.md) your microcontroller. 
This step may seem confusing but just follow the page carefully and it'll start making sense.
7. Setup your modem (if necessary for your configuration) according to manufacturers instructions. 
Often this just means activating your sim card on the company website and plugging it into the usb 
modem.
8. [Test](assemble/testing.md) your sensors. Make sure everything is working before you put it into 
the 3d-printed assembly.
9. [Assemble](assemble/core.md) your station. Put all the pieces together and give it a quick test 
before putting it in the field.
10. [Deploy](deploying/home_deployment.md) your station. Follow the steps for choosing a proper site and 
put your new weather station out in the field.

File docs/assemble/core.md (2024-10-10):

# Assembling the Main Unit
At this point you should have confirmed your sensors, wiring, microcontroller, connection, and power source are functional. Now we will disconnect the wiring we put together for testing so that we may get each component into its housing, then fit all the housing together.

The instructions on this page are to assemble a basic model of the IoT weather station with four sensors: rain gauge, air quality, temperature/pressure/humidity, and UV. We encourage you to explore and iterate on this design once you understand the principle structure. If you would like to add more sensors, any Qwiic compatible, I2C, sensors can be daisy-chained or connected to another splitter if needed.

## Housing Assembly

1. **Hydreon RG15 Rain Sensor**

     |Parts|||
     | ------ |  ------ |   ------ | 
     |Rain gauge wired with GPIO to Grove cable<br>Screws from original rain gauge base|3D printed rain gauge mount|Screwdriver|

     |Instructions | Image|
     | ------ | ------ |
     |Detach the rain gauge from the microcontroller by pinching down on the white tab (open the alligator mouth) and pulling it off. |![](){: style="display: block; margin: 0 auto; width: 200px;"}|
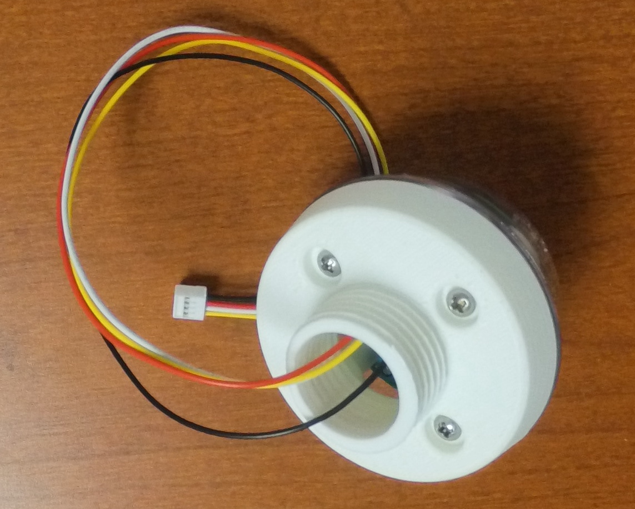
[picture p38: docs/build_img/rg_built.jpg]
rg complete
     |Insert the cords through the center of the rain gauge base and align the base with the four screw holes in the board. Reattach the housing with the screws you removed from the manufacturer's base. Note: it is not required to keep the silica packet in. The purpose of the packet is to absorp water that may get into the sensor. |  |

2. **Air Quality Sensor Housing**

     |Parts|||
     | ------ |  ------ |   ------ | 
     |AQ Sensor wired with 200mm qwiic wire|AQ Base|AQ vented cap|

     |Instructions | Image|
     | ------ | ------ |
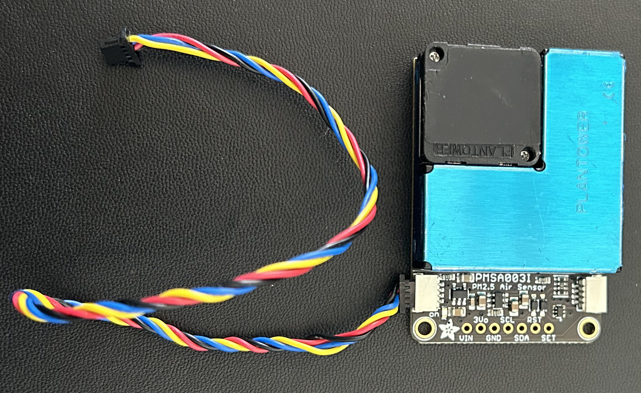
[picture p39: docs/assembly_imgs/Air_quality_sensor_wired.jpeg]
AQ Sensor Wired
     |Unplug the air quality sensor from the Qwiic connector, but leave the cord connected to the sensor.||
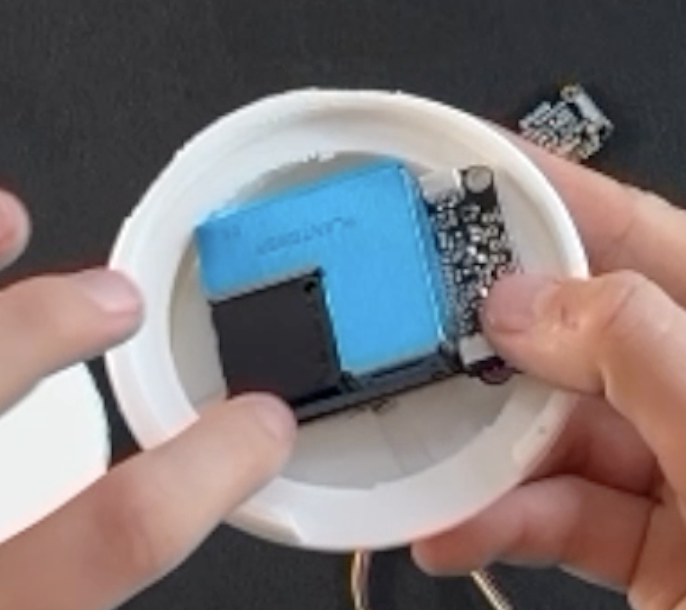
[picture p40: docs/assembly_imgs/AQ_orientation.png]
AQ Orientation
     |Find the fan on the sensor (looks like a small black box). Feed the air quality wiring through the vented base and make sure the fan is facing towards the bottom of the housing (Look for the gap/lip at the bottom of the vented lid). ||
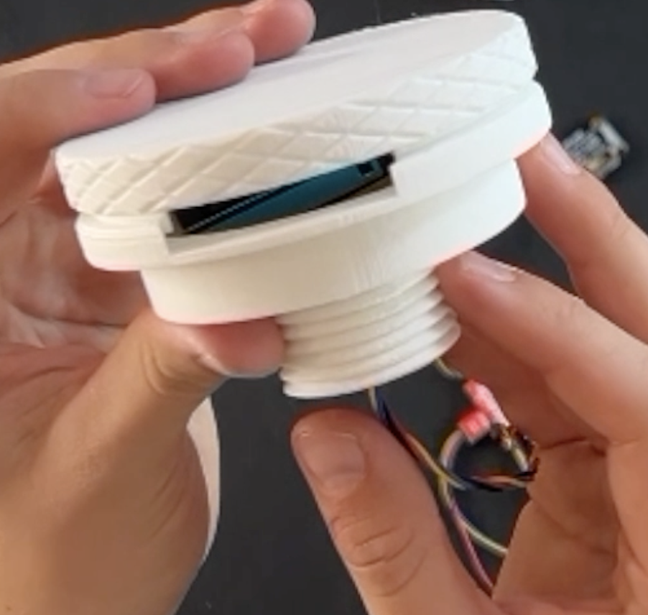
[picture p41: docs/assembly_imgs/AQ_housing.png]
Finished Air Quality Housing
     |Twist on the vented lid. You should be able to see the fan at the bottom of the housing. NOTE: It may be a little difficult to twist on the vented lid. You may need to snap it into place. ||

3. **Temperature, Humidity, and Air Pressure (BME680) Housing**

     |Parts|||
     | ------ |  ------ |   ------ | 
     |BME680 wired with 100mm qwiic wire|Radiation Shield|Vented Cap|

     |Instructions | Image|
     | ------ | ------ |
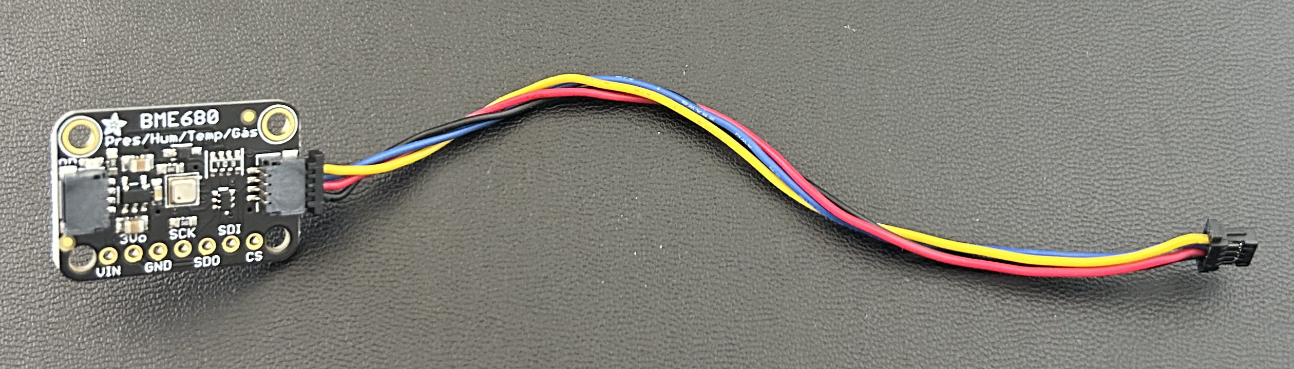
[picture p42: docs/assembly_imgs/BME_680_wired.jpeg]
BME680 Sensor Wired
     |Unplug the BME680 sensor from the Qwiic connector, but leave the cord connected to the sensor.||
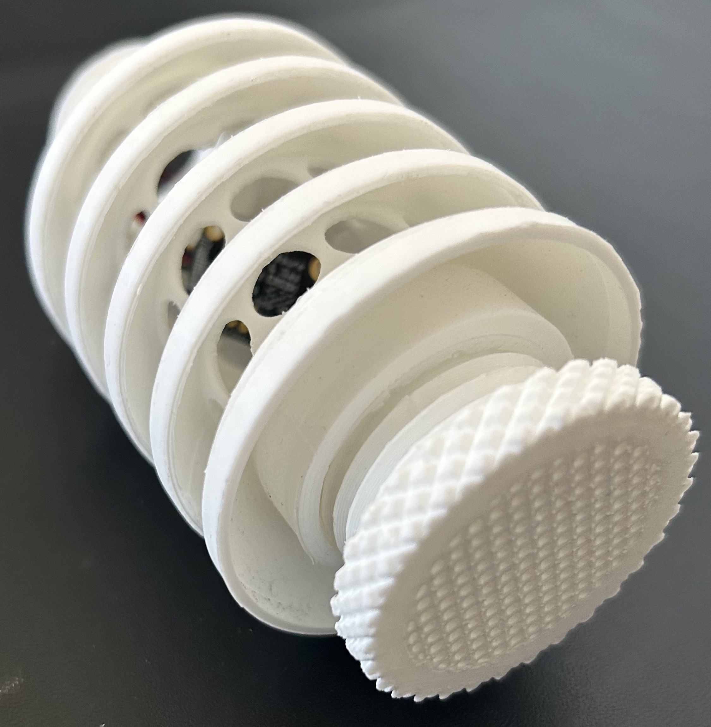
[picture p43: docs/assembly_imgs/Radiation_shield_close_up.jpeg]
Vented Cap of Radiation Shield
     |Screw the vented cap onto the bottom of the radiation shield. ||
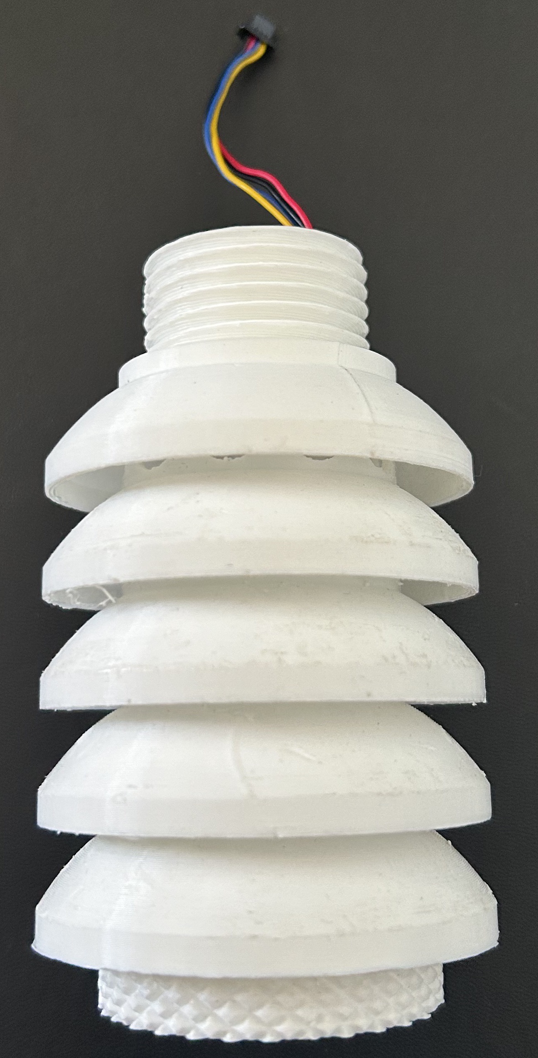
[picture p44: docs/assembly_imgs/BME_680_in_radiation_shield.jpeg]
radiation built
     |Gently place the temperature, humidity, and air pressure sensor (BME 680) into the radiation shield with the wires sticking out from the top opening. |  |

4. **UV Sensor Housing**

     |Parts|||
     | ------ |  ------ |   ------ | 
     |UV sensor wired with 500mm qwiic wire<br>UV cap<br>UV tube|1" PVC T pipe<br>Short length of 1" PVC<br>Threaded to PVC adaptor|Lens cover<br>Glue|

     |Instructions | Image|
     | ------ | ------ |
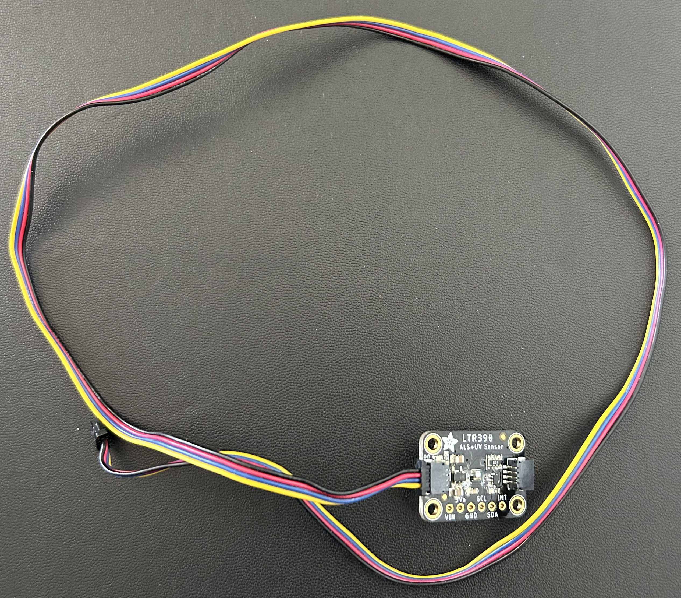
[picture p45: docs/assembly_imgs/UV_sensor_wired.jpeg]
UV Sensor Wired
     |Unplug the UV sensor from the Qwiic connection port, but leave it wired to the sensor.||
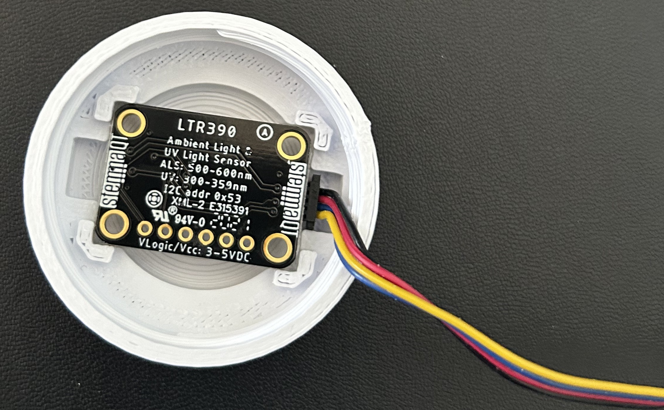
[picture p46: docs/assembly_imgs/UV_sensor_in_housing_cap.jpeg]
UV Sensor in Housing Cap
     |Position the sensor in the UV cap so that the sensor-side is visible through the cap’s hole.||
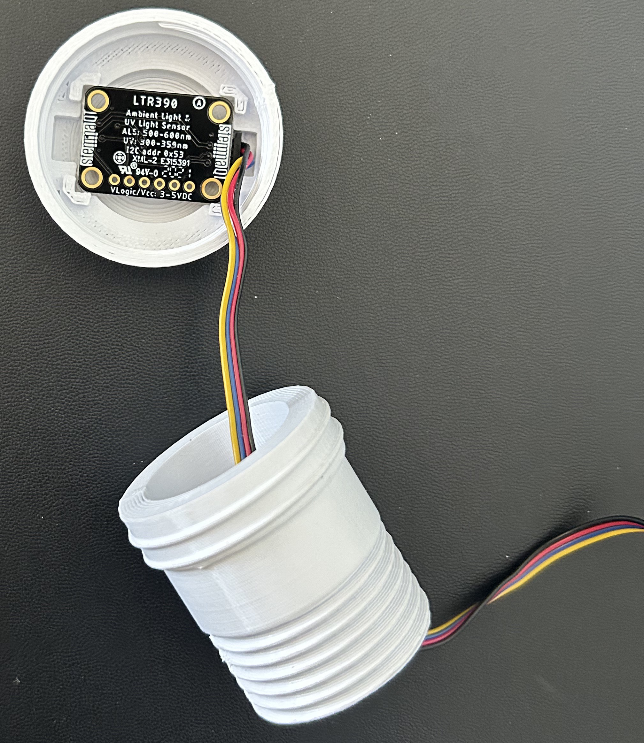
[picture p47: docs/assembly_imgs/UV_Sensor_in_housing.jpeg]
Adding base to UV sensor
     |Thread the sensor wires through the UV base and screw the base onto the UV cap. ||
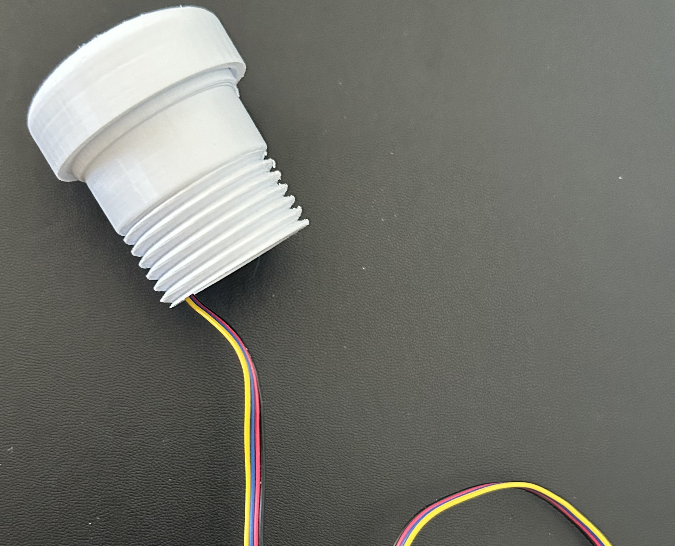
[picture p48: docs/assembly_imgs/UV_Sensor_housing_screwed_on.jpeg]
UV sensor with base and cap
     |The sensor should feel very secure even when you tug on the wire. Double-check that the sensor-side of the UV sensor is visible from the top of the cap. ||
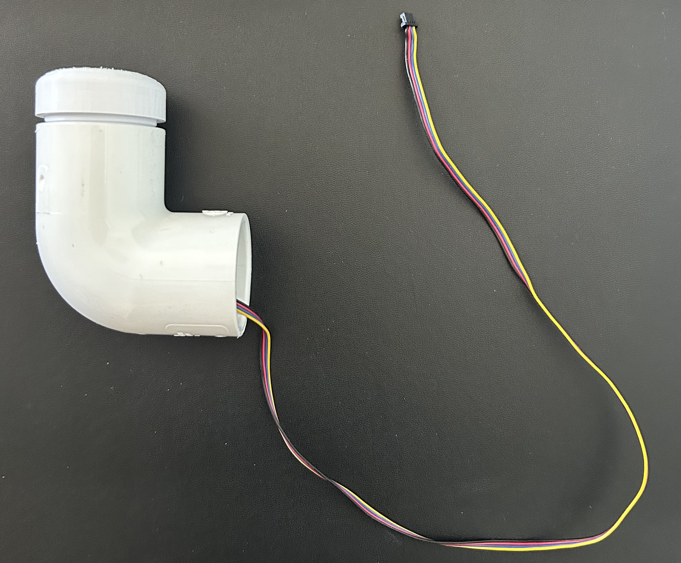
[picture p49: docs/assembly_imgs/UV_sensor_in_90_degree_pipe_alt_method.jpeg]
UV in PVC Joint
     |Thread the UV sensor wire through the top of the PVC joint and out the side side. Then, fit the UV base and cap onto the top of the PVC joint. ||
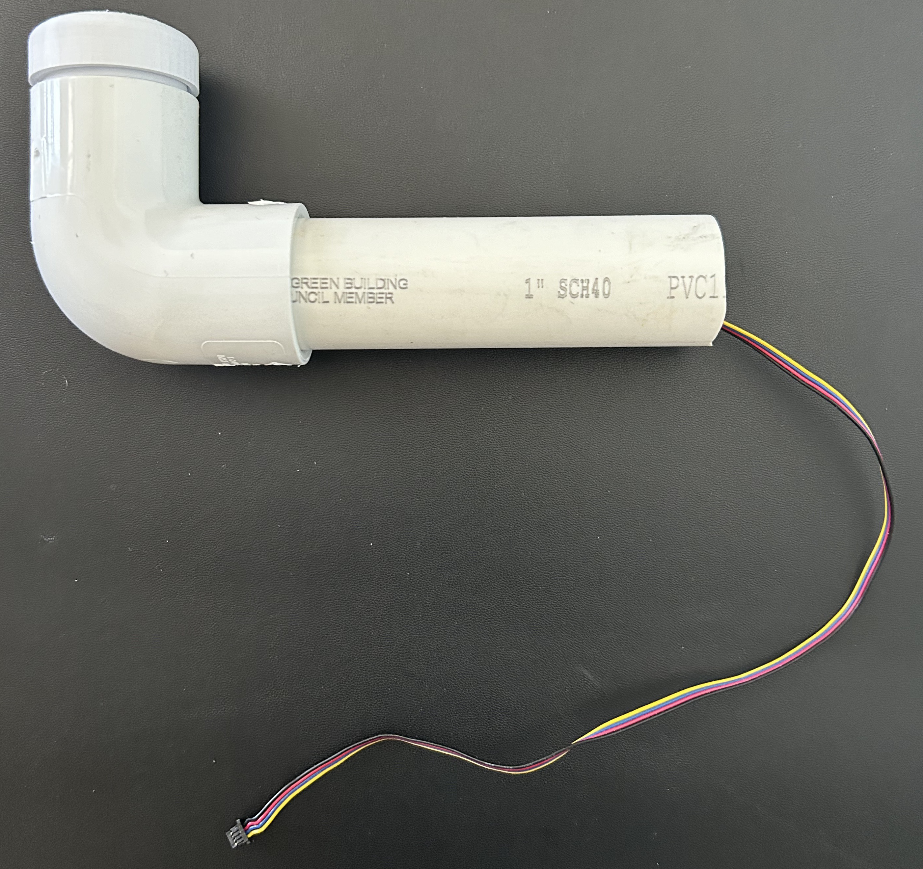
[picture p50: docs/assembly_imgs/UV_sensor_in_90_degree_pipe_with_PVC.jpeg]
UV with PVC Attached
     |Attach the shortest PVC pipe to the PVC joint and thread the wire through.||
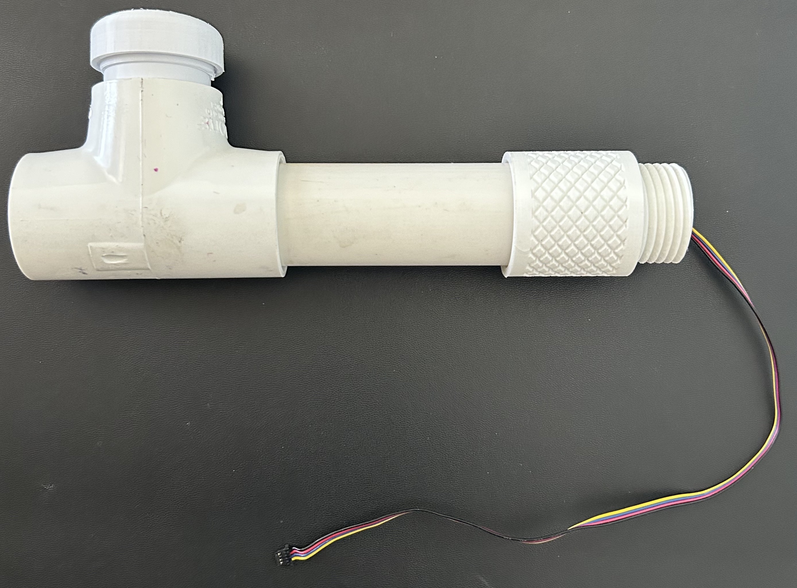
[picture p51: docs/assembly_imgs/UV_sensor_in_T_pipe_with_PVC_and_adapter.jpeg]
UV full set up with adapter
     |Attach the final UV sensor 3D printed piece, which is the threaded attachment piece, to the end of the short PVC pipe (find in Print/Key Accessories).||
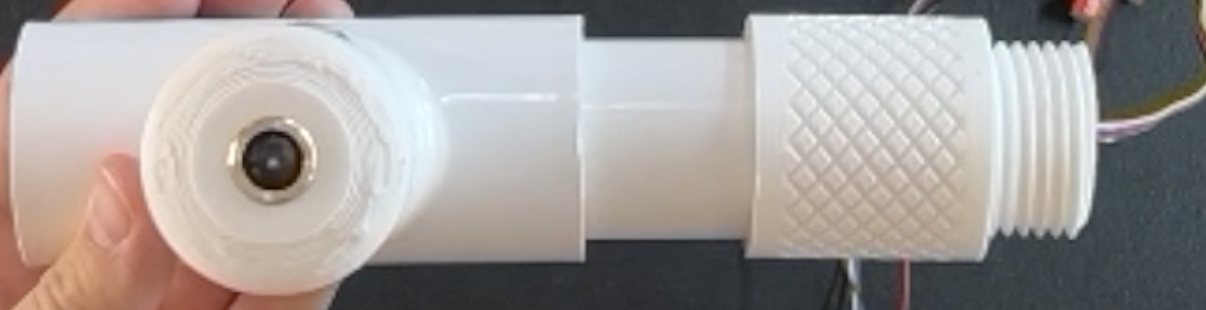
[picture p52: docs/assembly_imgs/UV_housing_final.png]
UV Housing Fully Assembled
     |Remove any film covering the screen of the UV lens. Place the lens over the top of the UV sensor housing. If it does not stay in place, consider using hot glue or another adhesive to ensure it remains secured. ||

## Final Assembly for Base Unit
Prior to starting the final assembly, ensure that the UV sensor, air quality sensor, rain gauge, and temperature, humidity, and air pressure sensor are all inside their respective housing and the microcontroller is properly wired. 

1. **Rain Gauge Attachment**

     |Instructions | Image|
     | ------ | ------ |
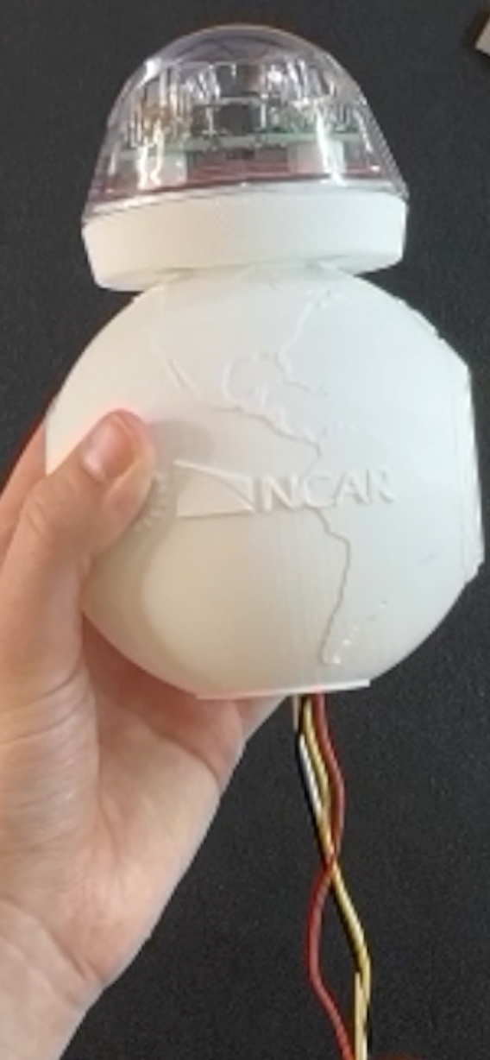
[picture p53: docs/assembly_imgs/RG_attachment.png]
Rain Gauge Attatchment
     |Thread the rain gauge wire through the upper opening of the orb housing (locate the labeled section of the orb housing and make sure it is facing the correct way) and fasten the rain gauge onto the orb housing by twisting it into the threading. Ensure the wires are sticking out from the bottom opeing of the orb.| |

2. **Air Quality Sensor Attachment**

     |Instructions | Image|
     | ------ | ------ |
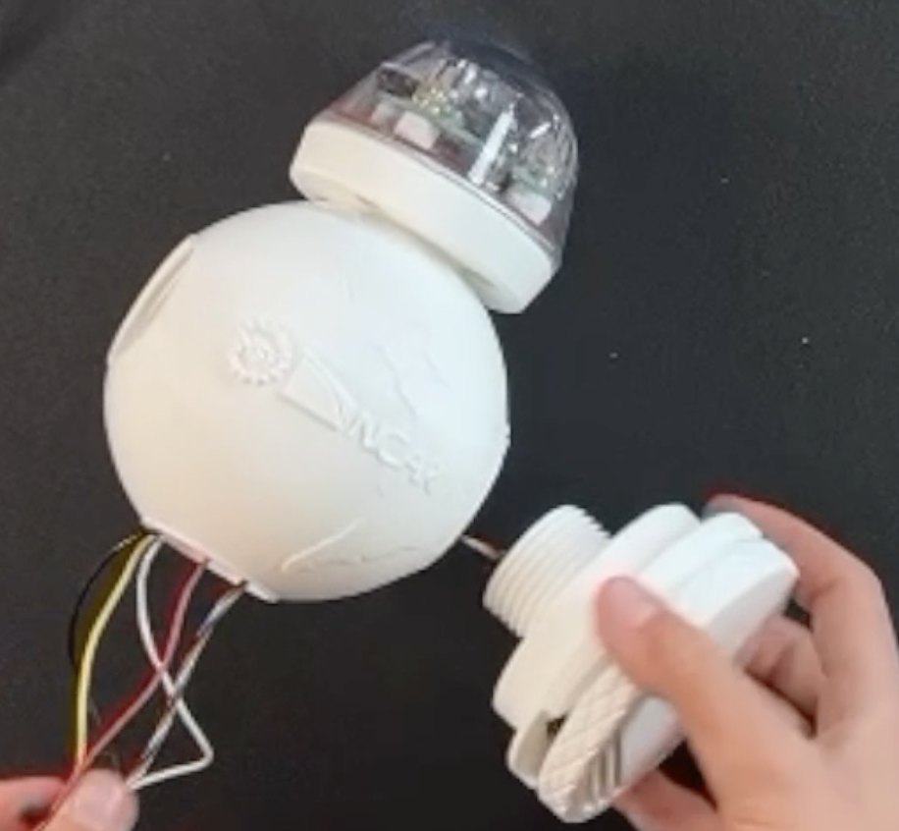
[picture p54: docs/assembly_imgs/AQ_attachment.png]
Air Quality Sensor Attatchment
     |Position the orb housing so that the “NCAR” label is visible to you. Thread the air quality sensor wires through the right-side opening and of the orb housing and out through the bottom. ||
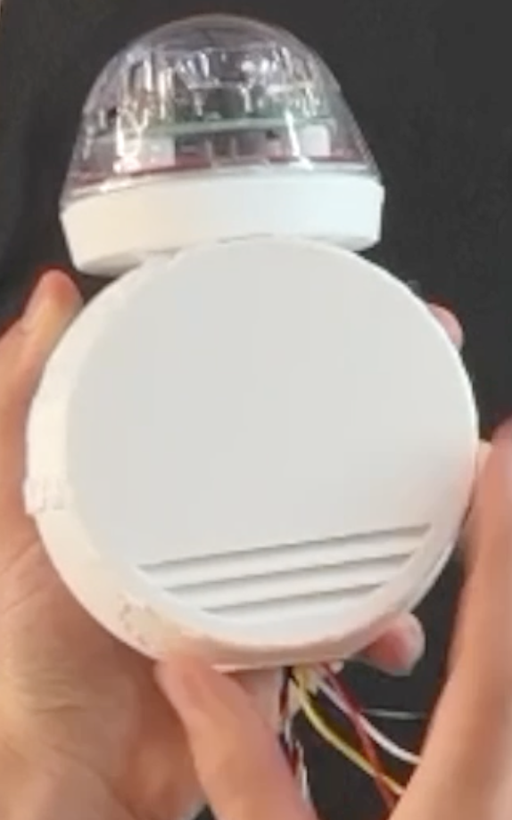
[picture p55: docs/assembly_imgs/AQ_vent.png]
Air Quality Vent Orientation
     Now screw on the air quality sensor to secure it. Be sure the vent section is correctly aligned at the bottom. | |

3. **UV Sensor Attachment**

     |Instructions | Image|
     | ------ | ------ |
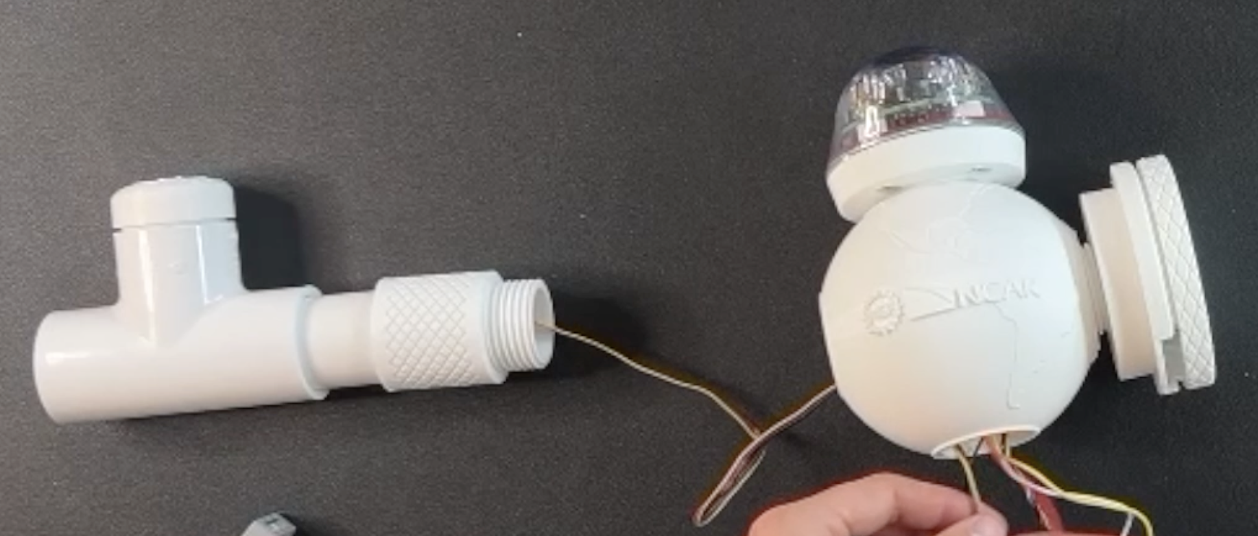
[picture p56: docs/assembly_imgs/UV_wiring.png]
UV Sensor Wiring
     |Thread the UV sensor wire through the opposite side of the orb housing to the air quality sensor, guiding it out through the bottom orb opening. |
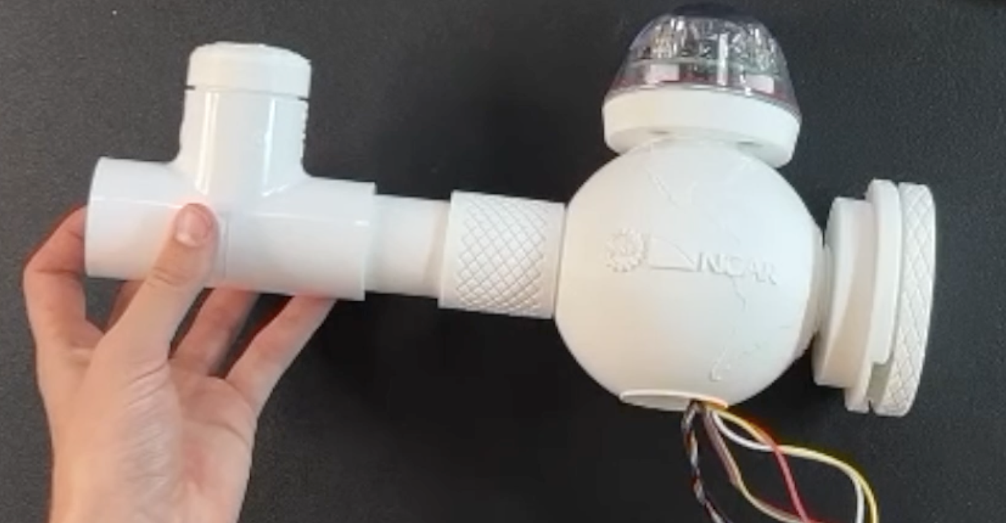
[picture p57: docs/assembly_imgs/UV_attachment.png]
UV Sensor Attachment
     |Align the threads of the printed PVC adaptor piece and securely twist the in place. Now you should have your UV sensor sitting in a PVC T-pipe junction and connected to the main orb with another length of PVC. Ensure you have three wires coming out the bottom of the orb: the rain gauge wire, the air quality sensor wire, and the UV sensor wire.|

4. **Power Cord Attachment**

     |Instructions | Image|
     | ------ | ------ |
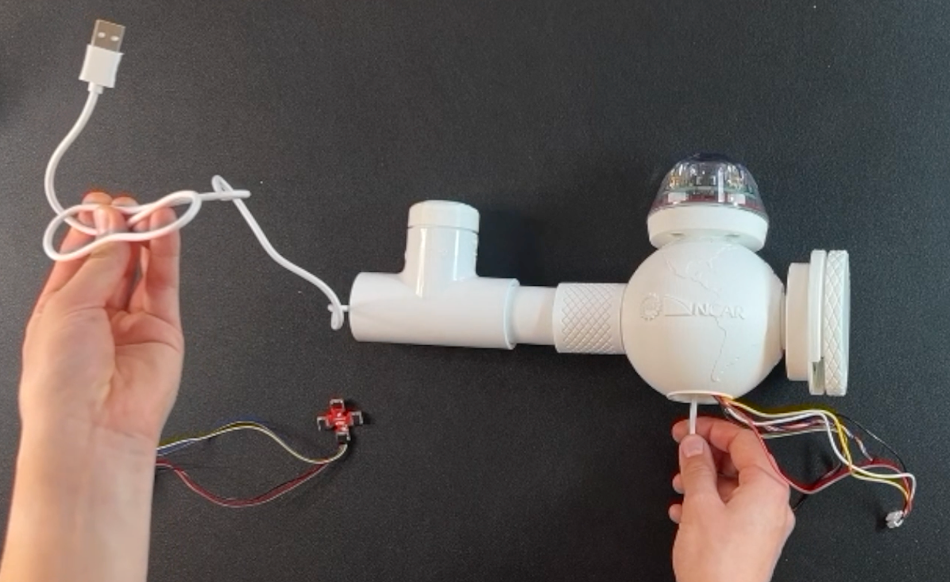
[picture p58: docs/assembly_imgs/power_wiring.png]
Power Cord Wiring
     |Insert the USB-C cord into the UV sensor's PVC pipe and through the bottom of the orb housing. Leave the USB side sticking out of the PVC pipe.||

5. **Connecting all the wiring**

     |Instructions | Image|
     | ------ | ------ |
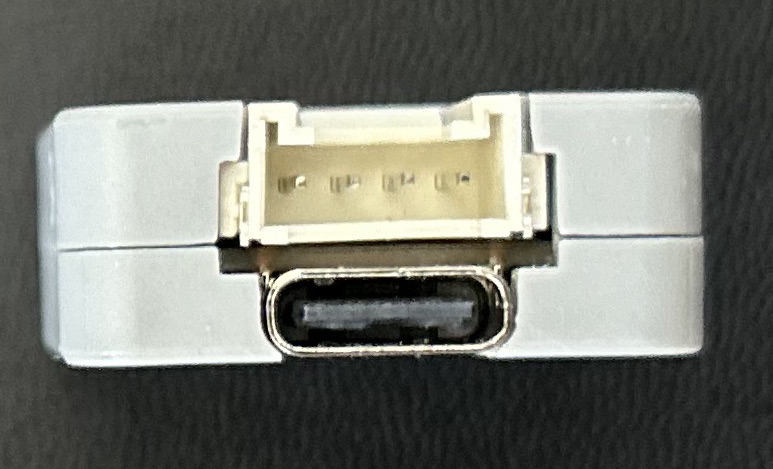
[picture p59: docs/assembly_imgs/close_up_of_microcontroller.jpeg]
Microcontroller Ports
     |Find the rain gauge connector and connect it into the microcontroller (look for white with 4 prongs). Then, connect the USB-C power to the microcontroller right below it.||
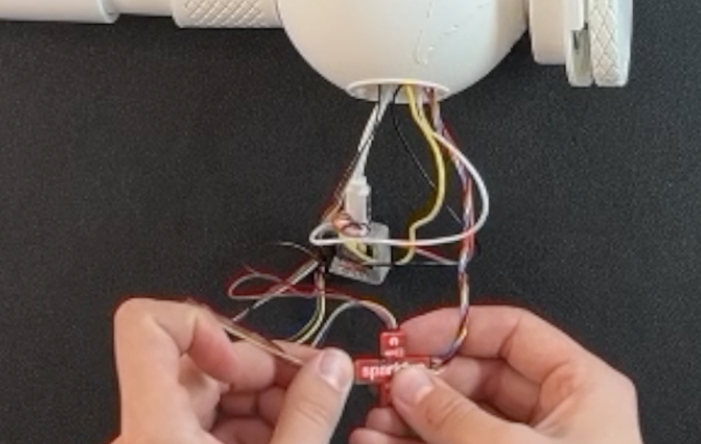
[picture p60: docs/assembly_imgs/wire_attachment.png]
Connect Wires
     |Connect the remaining two wires (air quality sensor and UV sensor) to the Qwiic MultiPort. The side of the port does not matter as long as the connection is tight. Attach the last sensor (BME 680 for temperature, humidity, and air pressure) to the Qwiic connection and keep track of this sensor.||
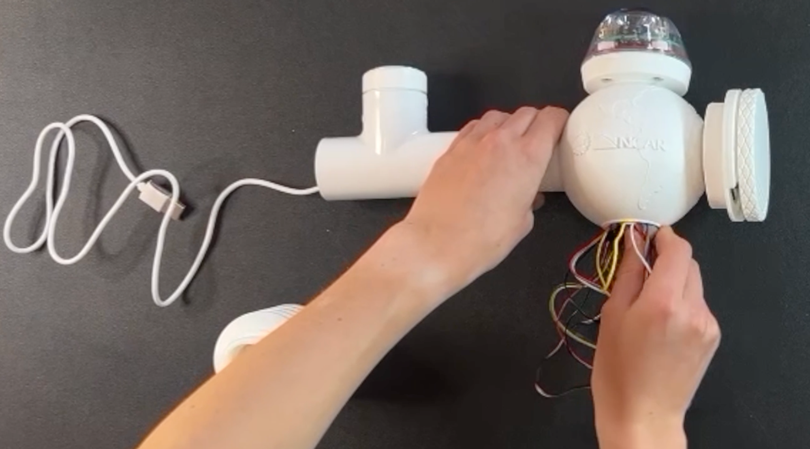
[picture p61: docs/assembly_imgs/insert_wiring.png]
Insert Wiring into Orb
     |Push all the sensors into the orb housing, except for the BME 680 sensor. Leave the BME 680 sensor outside the orb housing temporarily. ||
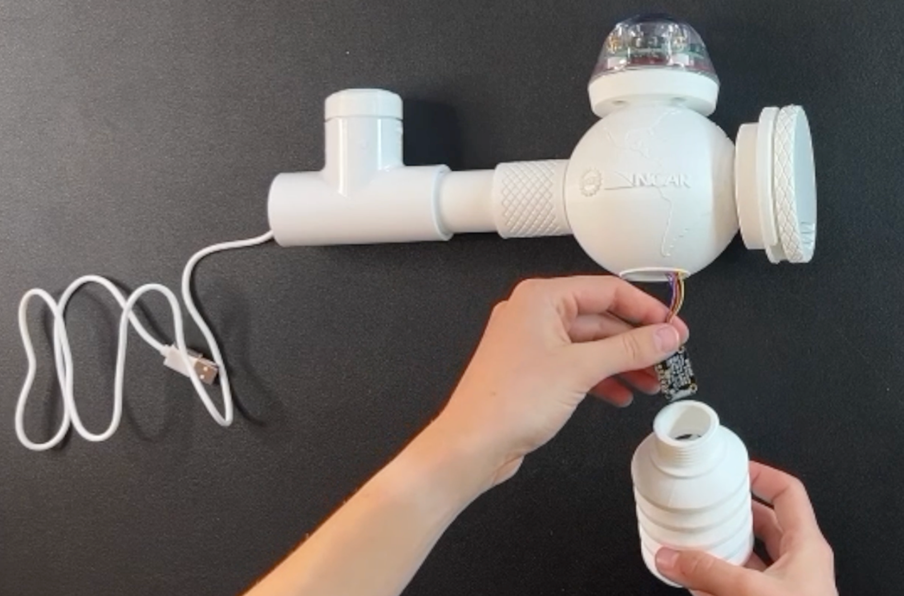
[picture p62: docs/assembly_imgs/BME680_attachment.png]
Attach Radiation Shield
     |Secure the radiation shield by place the BME 680 sensor inside the shield and screwing the shield to the bottom of the orb housing.||
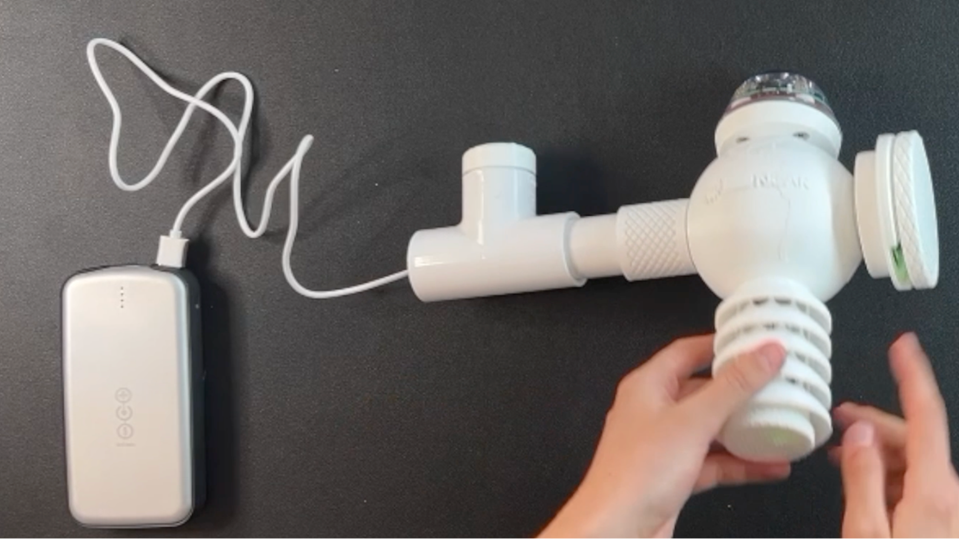
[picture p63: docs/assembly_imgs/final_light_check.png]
Test Final Assembly
     |Once you have completed the base assembly, you can test the complete core unit. Take your power source and plug-in the USB cord. You should see multiple green lights from the air quality sensor, radiation shield, and the UV sensor. It may be helpful to dim the lights to see the green glows. You may also be able to see the orb glowing red. ||

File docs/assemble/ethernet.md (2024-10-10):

#Connecting and Powering your Station over Ethernet

Coming soon

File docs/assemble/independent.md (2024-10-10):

#Assembling Independent Power and Connection for your Station

## Solar and Power Installation for an Independent Weather Station

1. **Setting Up the Solar Panel Mounts**

     |Parts|||||
     | ------ |  ------ |   ------ |   ------ |   ------ | 
     |1” PVC pipe|2 PVC mounts with pilot holes|2 Screws|Screwdriver|Solar panel|

     |Instructions | Image|
     | ------ | ------ |
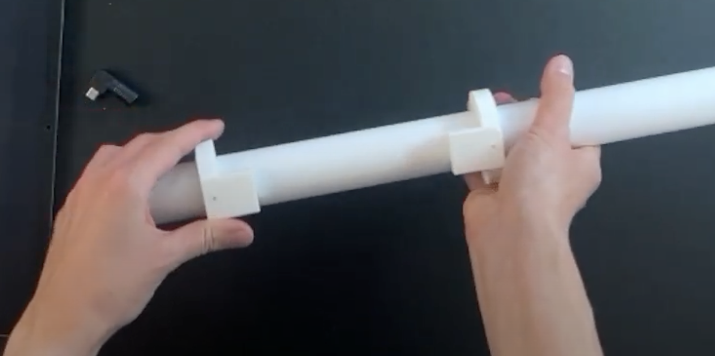
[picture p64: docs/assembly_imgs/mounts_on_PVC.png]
PVC mounts on PVC pipe
    |Pre-drill pilot holes into the outward-facing flat face of the printed PVC mounts if you have not already done so. Then, slide the PVC mounts onto the PVC.| |
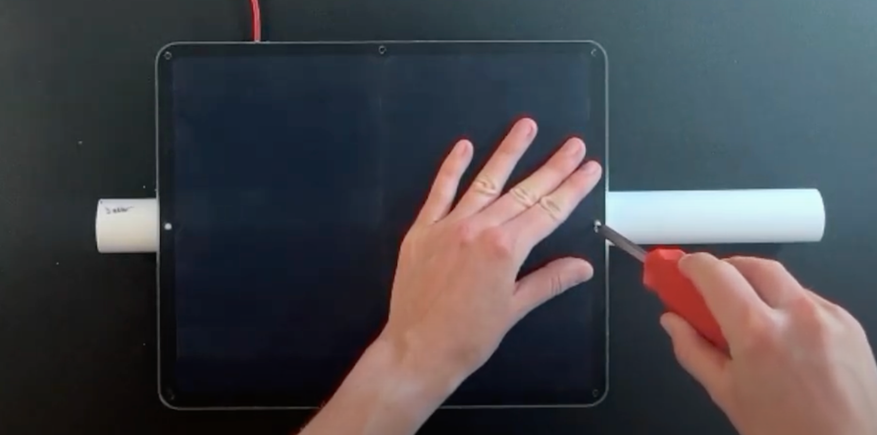
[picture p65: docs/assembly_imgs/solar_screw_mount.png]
Attaching mounts to solar panel
    |Align one screw hole on the solar panel with the pilot hole on the PVC mount and screw it on. Do the same on the other side.|  |
    |Slide the solar panel off of the PVC pipe and set aside. If it is hard to slide off, try loosening the screws.| ![](){: style="display: block; margin: 0 auto; width: 200px;"} |

2. **Wiring the Junction Box**

     |Parts|||
     | ------ |  ------ |   ------ |
     |Wifi modem<br>Junction box<br>USB to USB connector|USB-C to USC power cord (already wired to microcontroller)<br>Solar panel<br>Solar panel adaptor|Screwdriver<br>Battery|

     |Instructions | Image|
     | ------ | ------ |
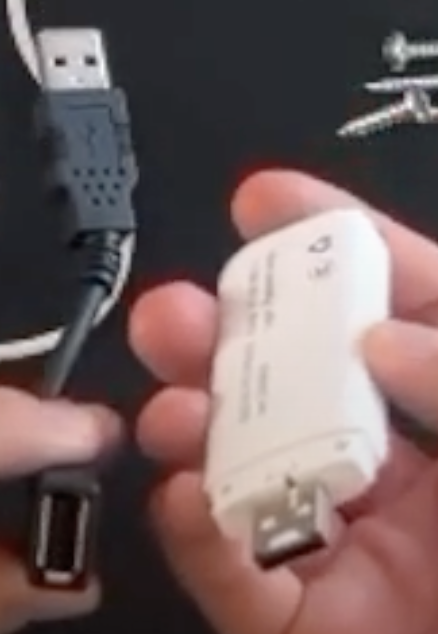
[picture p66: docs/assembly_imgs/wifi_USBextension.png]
Wifi modem and USB extender
     |Plug your USB wifi modem into your USB to USB adaptor. This will allow the modem fit better into the junction box when the time comes. Set aside.||
     |Unscrew the lid to your junction box and the cap of the hole drilled into the junction box. Run the USB end of the USB-C to USB Power cord into the box, feeding it through the cap you unscrewed from the hole in the junction box. If your hole is too small to fit the USB end, you may have to unplug the USB-C end from the microcontroller and feed it through the junction box's hole from the inside. If you do this, wait to reconnect the cord to the microcontroller. until you have finished installing your junction box.|![](){: style="display: block; margin: 0 auto; width: 200px;"}|
     |Feed the solar panel cord from outside the box, in, going through the cap and the hole. Once inside, plug the end of the solar panel cord into the provided adaptor. Make sure it is a tight fit.|Solar and Power Cords in Junction Box|
     |Re-screw cap over the hole into the junction box.|Reattatched cap over wires into junction box|
     |Plug your hotspot and power cord into the USB ports of your battery. You will need to use the adapter for the power cord. Plug your solar cord into the side of the battery in the appropriate port.|Battery with solar, wifi, and power plugged in|
     |Push all contents of your junction box inside so they are below the top of the box. Tuck any excess cord length into the box. Align the junction box lid with the junction box and screw in into place.|Closed junction box|

3. **Setting Up the Junction Box Mounts**

    |Parts|||||
    | ------ |  ------ |   ------ |  ------ |   ------ |
    |Wired junction box|1" PVC pipe|2 PVC mounts with pilot holes|2 Screws|Screwdriver

    |Instructions | Image|
    | ------ | ------ |
    |Pre-drill pilot holes into the outward-facing flat face of the printed PVC mounts if you have not already done so. Then, slide the PVC mounts onto the PVC.| PVC mounts on PVC pipe|
    |Align one screw hole on the junction box with the pilot hole on the PVC mount and screw it on. Do the same on the other side.|Attatching the PVC mounts to the junction box|
    |Slide the junction box off of the PVC pipe and set aside. If it is hard to slide off, try loosening the screws.|Junction box with mounts attached|

4. **Solar and Junction Box Installation**

    |Parts|||||
    | ------ |  ------ |   ------ |  ------ |   ------ |
    |Wired junction box with mounts|Solar panel with mounts|1” PVC pipe|Screwdriver|

    |Instructions | Image|
    | ------ | ------ |
    |Slide the **first** mount for the solar panel onto the PVC pipe. Then, slide **first** mount for the junction box onto the PVC pipe with the junction box resting on the opposite side as the solar panel. The first mount for the junction box should be on the opposite side of the hole where the wiring exits. |First mounts of solar panel and junction box on PVC pipe|
    |Now slide on the **second** solar mount, then the **second** junction box mount. Feed the USB-C end of the power cable into and through the PVC, coming out on the side of the pipe that will be closest to the core unit once fully assembled. You will need to disconnect the USC-C end of the power cable from the microcontroller to complete this step if you have not done so already.|Solar panel and junction box fully mounted to PVC pipe|
    |Once you have the solar panel and junction box exactly where you want them, tighten the screws on their mounts. |Tighening screws on solar panel and junction box|

5. **Final Assembly**

     **Note: Exactly how you execute your final assembly will depend in part of how you plan to deploy your weather station. Consider if you want to place it on a pole in the ground or attach it to something like a fence. You will want to configure your mounting to match your intended mounting area.**

    |Parts||
    | ------ |  ------ |
    |PVC pipe with mounted Solar and Juntion Box<br>PVC pipe|Completed Core Weather Station<br>UV addition to Station|

    |Instructions | Image|
    | ------ | ------ |
    |If you would like your UV sensor to sit if a different position than it did during core unit assembly, reposition it now. Be sure to run the wire for the sensor back into the Qwiic multiport if you adjust the sensor's position.|UV Sensor Reconfiguration|
    |Run the power cord from where it emerged out of the power/solar pipe into the microcontroller in the core weather station|Run power cord back to micrtocontroller|
    |Add whatever PVC configuration you need to mount your weather station. In this case, the station will be mounted on a pole into the ground, so a long PVC pipe is added extending downward.|Completed weather station|
    
    Your weather station is complete and ready for deployment!

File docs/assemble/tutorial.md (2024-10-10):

# Video Tutorials

Here, you’ll find step-by-step videos that complement our written and photographic instructions for building your weather station. These tutorials offer a visual guide to help you navigate the assembly process, providing helpful tips and insights along the way. You can build the weather station's core unit and power by watching these videos or following our written instructions in the next pages, or by using both as a resource.

[Core Station Assembly Tutorial:](https://www.youtube.com/watch?v=e8jn9YEWNgk)
This video contains instructions to assemble a basic model of the IoT weather station with four sensors: rain gauge, air quality, temperature/pressure/humidity, and UV. We encourage you to explore and iterate on this design once you understand the principle structure. If you would like to add more sensors, any Qwiic compatible, I2C, sensors can be daisy-chained or connected to another splitter if needed.

[Solar Power and Internet Assembly Tutorial:](https://www.youtube.com/watch?v=dKPR-SjQvcQ)
This video contains instructions to add a solar panel, battery, and wifi modem to bring your station online. You can use alternate power and internet sources as well such as ethernet or connecting to an existing wifi network for cnnectivity.

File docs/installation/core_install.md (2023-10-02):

# Flashing Microcontrollers

Each station node is build with a microcontroller as its brain. Each
microcontroller is connected to one or more sensors either directly or
by hubs -- [Grove hubs](https://www.seeedstudio.com/Grove-I2C-Hub.html) or [Qwiic hubs](https://www.seeedstudio.com/Grove-Qwiic-Hub-p-4531.html). 

openIotWx is designed to be used with the [m5Stack Atom Lite](https://m5stack.com/collections/m5-core/products/atom-lite-esp32-development-kit)
ESP32-Pico based microcontroller, but it is possible to connect other microcontroller devices with a few modifications to the code. Technically _any_ ESP32 chip with enough memory would work.
That being said, the M5 atom lite is quite cheap and easy to purchase, and we thus suggest that one.

## IoTwx library installation

Before compiling the microcode onto the Arduino, you will also need to
install the IoTwx library which controls the
communications and initialization functions of the station.

!!! info  "IoTwx Library"

    The library can found at the following repository. It should be
    installed in your `Arduino/libraries` directory and once installed, you
    may use it by the `#include "IoTwx.h"` directive.

    * [https://github.com/NCAR/esp32-atomlite-arduino-iotwx](https://github.com/NCAR/esp32-atomlite-arduino-iotwx)

## Preparing Your System

First, download Arduino 1.8 - this is an old release but in order to use the correct data format, SPIFFS, you must use Arduino 1.8. Download Arduino 1.8.19 following this [link](https://www.arduino.cc/en/Main/Software). If this is changed in Arduino IDE, IoTWX will adapt accordingly. 

Next, Underneath the boards manager, download the Espressif add the following URL to the list of Boards Manager list so that "ESP32 Dev" appears via File->Preferences->Additional Boards Manager URLs
[https://raw.githubusercontent.com/espressif/arduino-esp32/gh-pages/package_esp32_index.json](https://raw.githubusercontent.com/espressif/arduino-esp32/gh-pages/package_esp32_index.json)

There are a few other steps you will need to complete:

Next, download the following packages. The easiest way to do this is to follow the github links and click download as zip. 
From there, in the ‘manage libraries’ functionality of Arduino (under sketch), you can add a library from a .ZIP. Do this with all packages that aren't native in the Arduino IDE library set.

* install the required ESP32 Pico / M5 Stack Atom lite boards; a comprehensive instruction set is [here](https://docs.m5stack.com/#/en/arduino/arduino_development)
* install the [arduino-esp32fs-plugin](https://github.com/me-no-dev/arduino-esp32fs-plugin) that will allow SPIFFS file uploads to ESP32 boards
* install the following libraries through the Arduino IDE or through the zip link:
    * MQTT library from 256dpi [https://github.com/256dpi/arduino-mqtt](https://github.com/256dpi/arduino-mqtt)
    * ArduinoJson library [https://github.com/bblanchon/ArduinoJson](https://github.com/bblanchon/ArduinoJson)
    * FastLED library [https://github.com/FastLED/FastLED](https://github.com/FastLED/FastLED)
    * NTPClient library [https://github.com/arduino-libraries/NTPClient](https://github.com/arduino-libraries/NTPClient)
    * Adafruit BME680 [https://github.com/adafruit/Adafruit_BME680](https://github.com/adafruit/Adafruit_BME680)
    * Adafruit LTR390 [https://github.com/adafruit/Adafruit_LTR390](https://github.com/adafruit/Adafruit_LTR390)
    * RG-15 Rain Gauge [https://rainsensors.com/docs/rg-guides/rg-arduino/hydreon-arduino-library/](https://rainsensors.com/docs/rg-guides/rg-arduino/hydreon-arduino-library/)
    * ESP Software Serial [https://github.com/plerup/espsoftwareserial](https://github.com/plerup/espsoftwareserial)
    * Adafruit Air Quality [https://github.com/adafruit/Adafruit_PM25AQI](https://github.com/adafruit/Adafruit_PM25AQI)
    * Adafruit SHT4x [https://github.com/adafruit/Adafruit_SHT4X](https://github.com/adafruit/Adafruit_SHT4X)
    * Wifi (Native in library)
    * Adafruit_Sensor [https://github.com/adafruit/Adafruit_Sensor](https://github.com/adafruit/Adafruit_Sensor)
    * I2C control [https://github.com/Sensirion/arduino-i2c-scd4x](https://github.com/Sensirion/arduino-i2c-scd4x)
    * DFRobot Ozone Sensor [https://github.com/DFRobot/DFRobot_OzoneSensor](https://github.com/DFRobot/DFRobot_OzoneSensor)
    * Sensirion Core [https://github.com/Sensirion/arduino-core](https://github.com/Sensirion/arduino-core)
    * M5 Ethernet [https://github.com/m5stack/M5-Ethernet](https://github.com/m5stack/M5-Ethernet)
    * The Custom IoTwx library

If ESP32 isn't appearing underneath the board manager, download it (see previous steps). 
Once ESP32 is downloaded, select it within board manager toolbar setting.
When selecting what board to use, under ESP32 Arduino, choose 'ESP32 Dev Module'

This will add a number of options underneath your tools section.
Select:

* Upload speed 115200
* CPU Frequency: 240
* Flash Frequency:80
* Flash mode: QIO
* Flash size: 4 MB
* Partition scheme: Huge APP
* PSram: disabled

Leave the rest as default if that setting was not already the default mode

## Cloning the file structure

Next, clone the [Github respository](https://github.com/NCAR/esp32-atomlite-arduino-base) into Arduino. 
Alternatively, click this link and download the zip of the file structure. 
There should be code, a data directory, and within the data directory, a config.json

## Editing Configuration Files

Your microcontroller must contain a user-customized configuration file to operate.  The file contains information about Network Connection (WiFi), MQTT (the way your station will send data) connections and some other relevant information.

The microntroller uses an [ESP32 SPIFFS filesystem](https://docs.espressif.com/projects/esp-idf/en/latest/esp32/api-reference/storage/spiffs.html) to store the configuration. 
In the folder that you will flash onto your mictrocontroller using the sketch data upload interface, you will find a `/data` folder which contains a `config.json` file. This config allows for identification and choice with upload destination.

If the data folder isn't appearing, don't worry. Just create a data folder in the Arduino sketch folder. Inside of that, put the json and contents in and it should work.

### Understanding the `config.json` file

A model config file looks something like this:

```json
{    
    "iotwx_local_config":"1",
    "iotwx_id":"m5atom/esp32/aaffbbcc",
    "iotwx_mq_ip":"",
    "iotwx_mq_port":"1883",
    "iotwx_publish_interval":"1",
    "iotwx_reset_interval":"360",
    "iotwx_sensor":"grove/i2c",
    "iotwx_timezone":"21600",
    "iotwx_wifi_pwd":"PASSWORD",
    "iotwx_wifi_ssid":"SSID",
    "iotwx_topic":"measurements/iotwx",
    "iotwx_max_frequency":"240"
}
```

The details of each key are described below.

| key | value / description |
|:--:|:---|
| `iotwx_local_config` | always set to "1" |
| `iotwx_id` |  contains a _unique_ identifier for you station as a whole.  This identifier is also used in the data portal. (e.g. `"iotwx-co-bb83"`) |
| `iotwx_mq_ip` |  the ip address (e.g. `"172.88.0.13"`) of the MQTT broker you will be using.  At the moment only one such broker is allowed. You may use the FQDN (`"mymqttsite.wx"`) but the IP address uses less power by reducing the time WiFi is on to do DNS lookups. |
| `iotwx_mq_port` |  the port number of the broker, which is typically `"1883"` for non-SSL and `"8883"` for SSL. |
| `iotwx_publish_interval` |  the interval you wish your station to transmit in _minutes_. Note: The stations only transmit when there is data to transmit. |
| `iotwx_reset_interval`| Minutes between system resets.  The nodes are designed to reset every 6 hours or twice daily.  Reset is instantaneous and the system is restored to full functionality in 90 seconds after the Bluetooth acquisition phase. (e.g. `"1"` for 1 minute) |
| `iotwx_sensor` | the sensor string for the node and may vary based on the node.  Typically do not change this value from what is contained in the default for your station. |
| `iotwx_timezone` | the GMT offset in seconds of the station timezone. (e.g. `"21600"`)|
| `iotwx_wifi_pwd` and `iotwx_wifi_ssid` | are the corresponding wifi password and ssid of the network your node will connect to.  Note, it is not necessary (but would be unusual) for all nodes to connect to the same WiFi network. (e.g. `"your_wifi"` and `"your_password"`)|
| `iotwx_topic` | the MQTT topic your node will publish to.  It is not necessary for all nodes to publish to the same topic, but if you are using the CHORDS MQTT Orchestrator ([GitHub - NCAR/chords-mqtt-orchestrator](https://github.com/NCAR/chords-mqtt-orchestrator)), then you will need to adjust it accordingly to route your messages where they belong.  The current default is `"iotwx/net"`. |
| `iotwx_max_frequency` | is the CPU frequency (in Mhz) you wish your node to run  on.  The m5Stack Atom Lite can be run from 40-240Mhz. Varying the value has power-saving benefits - up to 50% reduction in total power consumption. |

## Flashing onto the microcontroller

Once you have everything set up within Arduino IDE, compile everything you just did. If that works with no errors, plug the microcontroller into your computer, and flash onto it.
Additionally, make sure to do an ESP32 Sketch Data Upload (under Tools). This will upload your config.json. You don't need to reflash the whole microcontroller if you need to update the config, just redo this step.

## Configuring data upload

While this isn't necessarily under the direct purview of openIoTwx, and is more covered by whatever orchestrator and other clients you decide to use, it is worth noting that your topic in the config needs to then be matched and set up within your orchestrator and then in your data collection / visualization client (CHORDS for us).

You can learn more about CHORDS at [http://chordsrt.com](http://chordsrt.com).

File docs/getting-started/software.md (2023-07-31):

# Software

There are two softwares that will be necessary for all users. Arduino - to load, or flash, data onto the
microcontroller, and a printing software. The printing software our team uses is Ultimaker Cura, if the
printer you buy is incompatible with Cura, use whatever specific printing software your machine suggests.
If you choose to use a different microcontroller system, you may also need a different flashing environment,
but that is outside of the scope of this guide.

First, download Arduino 1.8.18. This is a legacy release but in order to use the correct data 
format, SPIFFS, you must use Arduino 1.8. SPIFFS has not yet been implemented in the 2.x version of Arduino. If this is changed in Arduino IDE, 
IoTWX will adapt accordingly.

Additionally you will need Ultimaker Cura (or a different 3d printing software)
to work with and edit the 3d files. 
You will need to edit them if you have special circumstances for 
your station site or you are using a different printer than the one we suggest. 
Our gcode files (instructions for the 3d printing) are calibrated with our printer, the Ender 3 S1,
and are too fickle to be worth sharing.

### Download pages:
[Arduino IDE](https://www.arduino.cc/en/software) (Scroll down until 'Legacy IDE')

[Ultimaker Cura](https://ultimaker.com/software/ultimaker-cura/#links)

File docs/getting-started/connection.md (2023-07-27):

# Power and Internet connection

## Power Options

To power your device, you have two primary options - a solar panel and battery or Power over Ethernet (PoE).

For a solar panel and battery, we are fans of [Voltaic](https://voltaicsystems.com/) because of their fairly high quality to price. 
That being said, there are many companies out there and if you can find a good deal, take it. The power source is only critical insofar as it exists, and the specific method shouldn't change anything.

For PoE we suggest integrating via an m5 microcontroller integration. What PoE does is both data transfer as well as internet, so it covers both realms.

## Internet Options

The methodology we have in use for remote stations is three pronged.

1. If there is service via a cellular network i.e T-mobile, Verizon, AT&T, etc. purchase a sim card with a long lifespan and a relatively small amount of data (we use 200mb for a year).Additionally purchase a USB modem. With these two options you can run a miniaturized wireless network that integrates perfectly with the ESP32 microcontroller and the MQTTdata protocol.
2. If there isn't cell service and funds are tight you can either store data locally and retrieve it - time-consuming
3. If there isn't cell service and there are available monies, set up a satellite network - significantly more expensive but easier.

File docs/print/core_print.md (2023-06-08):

# Printing out the station

Attached in this document are all of the .stl (3d printing files), .step
(3d design files), as well as the gcodes (what is input to the 3d printer directly), for every node. 
We suggest not to use the gcode unless using the same printer as our team,
the Creality Ender 3 S1. If you aren't just use Ultimaker cura with your printer 
settings to generate the gcode - quite easy.

## Base Unit

### Housing options

Dome Housing: stl link, step link, gcode link

Skinny housing: stl link, step link, gcode link 

### Base attachments

Rain gauge: stl link, step link, gcode link

UV: stl link, step link, gcode link

Radiation shield: stl link, step link, gcode link

Air Quality: stl link, step link, gcode link

Anemometer: stl link, step link, gcode link

## Auxiliary units

Camera: stl link, step link, gcode link

Lidar: stl link, step link, gcode link

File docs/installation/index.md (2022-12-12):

# Flashing Microcontrollers

Each station node is build atop a microcontroller, where each
microcontroller is connected to one or more sensors either directly or
by hubs -- [Grove hubs](https://www.seeedstudio.com/Grove-I2C-Hub.html) or [Qwiic hubs](https://www.seeedstudio.com/Grove-Qwiic-Hub-p-4531.html). 

IotWx is designed to be used with the [m5Stack Atom Lite](https://m5stack.com/collections/m5-core/products/atom-lite-esp32-development-kit)
ESP32-Pico based microcontroller, but it is possible to connect other microcontroller devices with small modifications to the codebase, though technically _any_ ESP32 chip with enough memory would work.

## Core IoTwx library installation

There are two nodes that the core Arduino code has been developed for.
Before compiling the microcode onto the Arduino, you will also need to
install the core IoTwx shared library which controls many of the
communications and initialization functions of each node.

!!! info  "IoTwx Core Library"

    The core library can found at the following repository. It should be
    installed in your `Arduiono/libraries` directory and once installed, you
    may use it by the `#include "IoTwx.h"` directive.

    * [https://github.com/NCAR/esp32-atomlite-arduino-iotwx](https://github.com/NCAR/esp32-atomlite-arduino-iotwx)

## Preparing Your System

You will need to install the [latest version of Arduino](https://www.arduino.cc/en/Main/Software) on your system to begin.

There are a few other steps you will need to complete:

* install the required ESP32 Pico / M5 Stack Atom lite boards; a comprehensive instruction set is [here](https://docs.m5stack.com/#/en/arduino/arduino_development)
* install the [arduino-esp32fs-plugin](https://github.com/me-no-dev/arduino-esp32fs-plugin) that will allow SPIFFS file uploads to ESP32 boards
* install the following libraries through the Arduino IDE:
    * MQTT library from 256dpi [https://github.com/256dpi/arduino-mqtt](https://github.com/256dpi/arduino-mqtt)
    * SeeedStudio VEML6070 library [https://github.com/Seeed-Studio/Seeed_VEML6070](https://github.com/Seeed-Studio/Seeed_VEML6070)
    * SeeedStudio BME280 library [https://github.com/Seeed-Studio/Grove_BME280](https://github.com/Seeed-Studio/Grove_BME280)
    * SeeedStudio BME680 library [https://github.com/Seeed-Studio/Seeed_BME680](https://github.com/Seeed-Studio/Seeed_BME680)
    * ArduinoJson library [https://github.com/bblanchon/ArduinoJson](https://github.com/bblanchon/ArduinoJson)
    * FastLED library [https://github.com/FastLED/FastLED](https://github.com/FastLED/FastLED)
    * NTPClient library [https://github.com/arduino-libraries/NTPClient](https://github.com/arduino-libraries/NTPClient)

## Editing and Flashing Configuration Files

Each node must contain a configuration file in order to operate.  The file contains information about WiFi connections, MQTT connections and some information about the node.

The [ESP32 SPIFFS filesystem](https://docs.espressif.com/projects/esp-idf/en/latest/esp32/api-reference/storage/spiffs.html) is used to store the configuration.  In the repositories of each node, you will find a `/data` folder which contains a `config.json` file.

### Understanding the `config.json` file

The typical config file  looks like this:

```json
{    
    "iotwx_local_config":"1",
    "iotwx_id":"m5atom/esp32/aaffbbcc",
    "iotwx_mq_ip":"",
    "iotwx_mq_port":"1883",
    "iotwx_publish_interval":"1",
    "iotwx_reset_interval":"360",
    "iotwx_sensor":"grove/i2c",
    "iotwx_timezone":"21600",
    "iotwx_wifi_pwd":"",
    "iotwx_wifi_ssid":"",
    "iotwx_topic":"measurements/iotwx",
    "iotwx_max_frequency":"240"
}
```

With details of each key described below.

| key | value / description |
|:--:|:---|
| `iotwx_local_config` | always set to "1" |
| `iotwx_id` |  contains a _unique_ identifier for you station as a whole -- that is to say, if you have multiple nodes on the same _physical station_, they would share the same `iotwx_id`.  This identifier is also used in the data portal. (e.g. `"iotwx-co-bb83"`) |
| `iotwx_mq_ip` |  the ip address (e.g. `"172.88.0.13"`) of the MQTT broker you will be using.  At the moment only one such broker is allowed. You may use the FQDN (`"mymqttsite.wx"`) but the IP address uses less power by reducing the time WiFi is on to do DNS lookups. |
| `iotwx_mq_port` |  the port number of the broker, which is typically `"1883"` for non-SSL and `"8883"` for SSL. |
| `iotwx_publish_interval` |  the interval you wish your station to transmit in _minutes_.  Note this is relevant primarily for the Atmos node which continuously transmits at the specified interval. Hydro and Aero nodes only transmit when there is data to transmit. |
| `iotwx_reset_interval`| the number of minutes between system resets.  The nodes are designed to reset every 6 hours or twice daily.  Reset is instantaneous and the system is restored to full functionality in 90 seconds after the Bluetooth acquisition phase. (e.g. `"1"` for 1 minute) |
| `iotwx_sensor` | the sensor string for the node and may vary based on the node.  Typically do not change this value from what is contained in the default for your node. |
| `iotwx_timezone` | the GMT offset in seconds of the station timezone. (e.g. `"21600"`)|
| `iotwx_wifi_pwd` and `iotwx_wifi_ssid` | are the corresponding wifi password and ssid of the network your node will connect to.  Note, it is not necessary (but would be unusual) for all nodes to connect to the same WiFi network. (e.g. `"your_wifi"` and `"your_password"`)|
| `iotwx_topic` | the MQTT topic your node will publish to.  It is not necessary for all nodes to publish to the same topic, but if you are using the CHORDS MQTT Orchestrator ([GitHub - NCAR/chords-mqtt-orchestrator](https://github.com/NCAR/chords-mqtt-orchestrator)), then you will need to adjust it accordingly to route your messages where they belong.  The current default is `"iotwx/net"`. |
| `iotwx_max_frequency` | is the CPU frequency (in Mhz) you wish your node to run  on.  The m5Stack Atom Lite can be run at frequencies up to 240, but has only been tested down 40 Mhz.  The AeroNode must be set to above `"160"` and runs best at `"240"`.  The Hydro node has been successfully configured at `"40"`  and the Atmos node's best performance is at `"80"`.  Varying the value has power-saving benefits, where we have seen 20-50% reduction in power consumption of a node. |

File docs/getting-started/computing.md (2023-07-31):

# Computing

A driving principle of OpenIoTwx is accessibility.
Because of this we have kept requirements low.

**Required**: Operating computer (because of our love for open source software,
we suggest Linux, Mac and Windows work as well), a monitor, a keyboard, and a mouse.  

Additionally, for the preliminary downloads, applications, etc, you will need a moderately stable
internet connection OR a flashdrive containing everything within the software 
and the core installation pages.

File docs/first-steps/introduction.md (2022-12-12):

---
title: Introduction
---

Aliquip amet laboris occaecat fugiat minim Lorem occaecat laboris pariatur anim officia.
Laborum pariatur ad deserunt ad aute aliquip ullamco mollit adipisicing non mollit.
Id et tempor et ad non officia et veniam.
Culpa quis magna eu ex labore excepteur elit quis.
Magna id nulla ullamco laborum eu cupidatat aliquip.

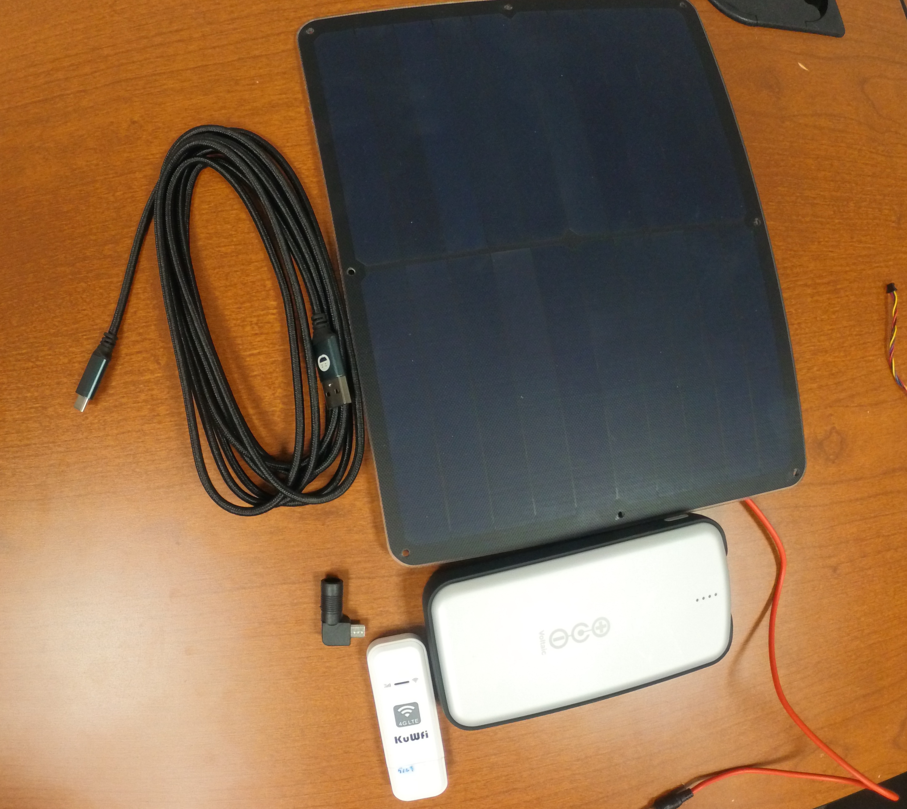
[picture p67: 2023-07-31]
docs/build_img/charging_process.jpg

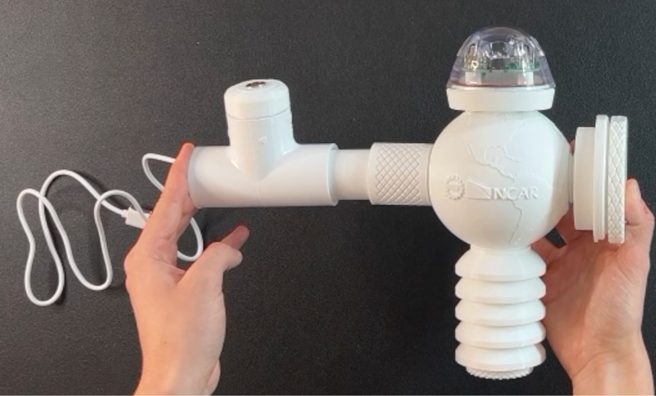
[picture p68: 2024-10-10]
docs/assembly_imgs/final_no_battery.png

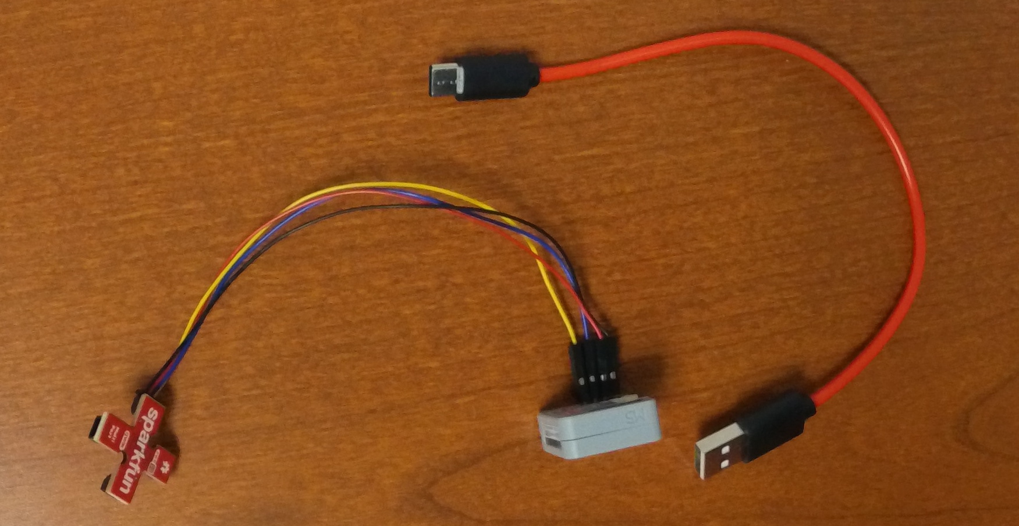
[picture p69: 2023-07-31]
docs/build_img/I2C_side.jpg

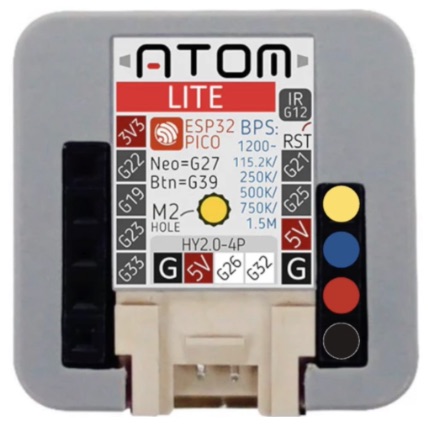
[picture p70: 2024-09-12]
docs/build_img/I2C_detail.jpeg

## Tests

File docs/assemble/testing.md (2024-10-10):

# Testing your Station Before Deployment 

Before you place all of your sensors into their various housing, it is important to test whether or not you are receiving data.

Here are the steps to do that most effectively:

1. Configure your wifi modem (if you are using a sim card setup)
2. Plug the modem into your power source and check whether or not you have a signal.
3. Unplug the modem and plug in your microcontroller, without any sensors attached. When connected to power, but not to sensors, it will blink red. 
4. Unplug the microcontroller from the power source and attach all your sensors with the appropriate cables. See the Microcontroller, Sensor, and Power Connections table below for details. 
5. Make sure all Grove and Qwiic connectors are properly pushed into place as this can cause issues down the line.
6. Without plugging in the modem, connect your microcontroller, with sensors attached, to the power source. If it flashes blue, you're clear to proceed.
7. Unplug the microcontroller, plug in the modem, wait a few seconds for your modem to connect, and plug in your microcontroller.
8. Wait a few minutes and then check your data portal to see if you are receiving data. If so, you are good assemble the station.

#### Microcontroller, Sensor, and Power Connections
|Connecting Items|Item 1 Image|Wire|Item 2 Image|Details|
|---|---|---|---|---|
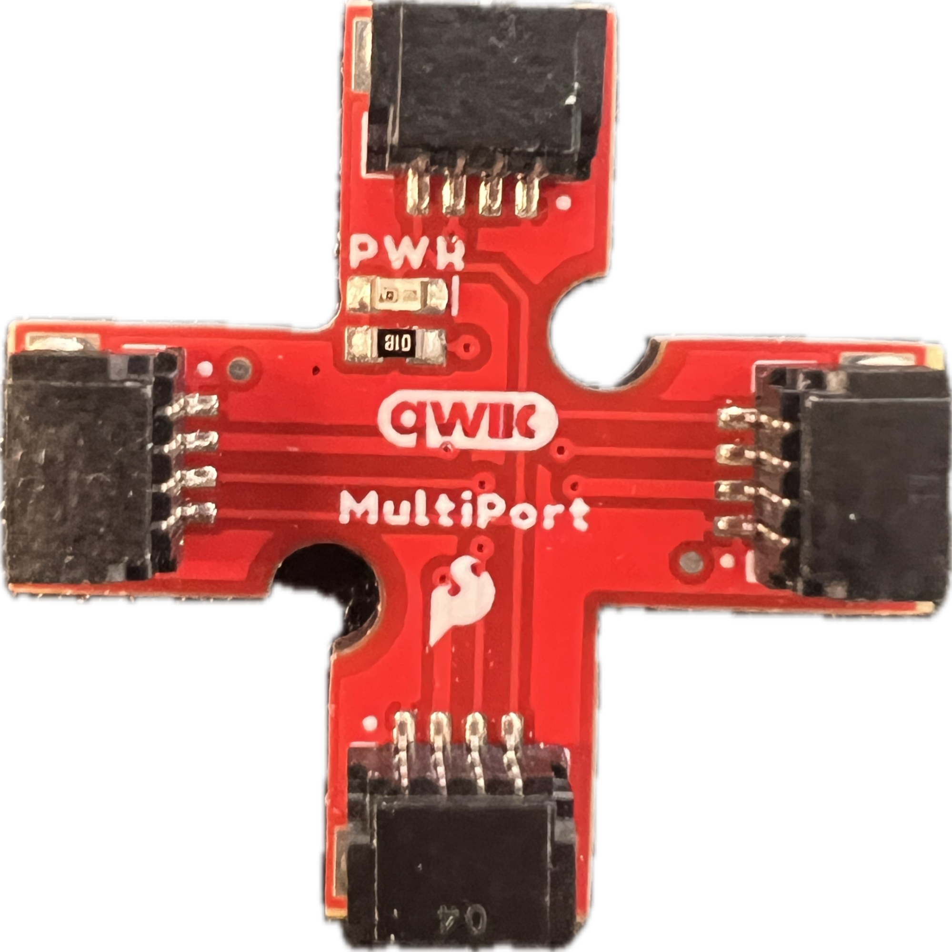
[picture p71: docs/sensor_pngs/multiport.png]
Qwiic MultiPort
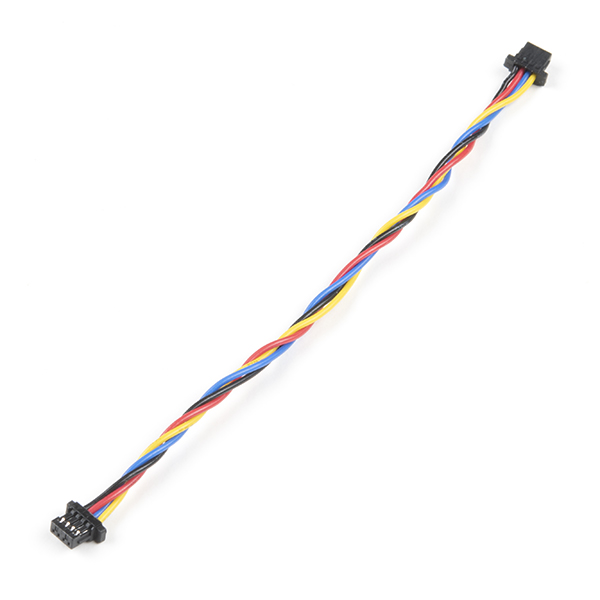
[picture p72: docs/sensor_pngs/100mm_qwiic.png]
100mm Qwiic Wire
|Qwiic MultiPort to BME680||100mm qwiic to qwiic wire|BME680||
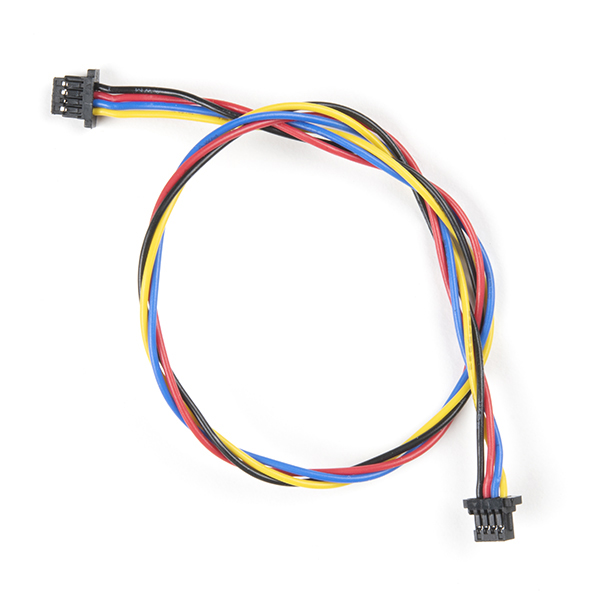
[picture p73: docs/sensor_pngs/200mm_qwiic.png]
200mm Qwiic Wire
|Qwiic MultiPort to Air Quality Sensor|Qwiic MultiPort|200mm qwiic to qwiic wire|Air Quality Sensor||
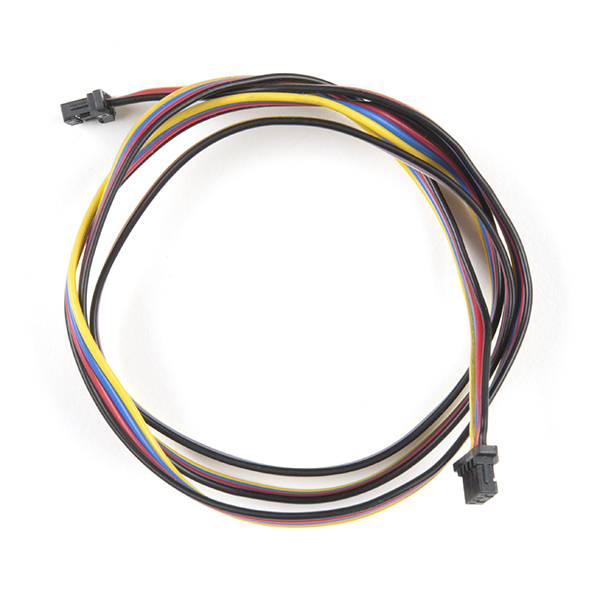
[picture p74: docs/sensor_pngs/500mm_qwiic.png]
500mm Qwiic Wire
|Qwiic MultiPort to UV Sensor|Qwiic MultiPort|500mm qwiic to qwiic wire|UV Sensor||
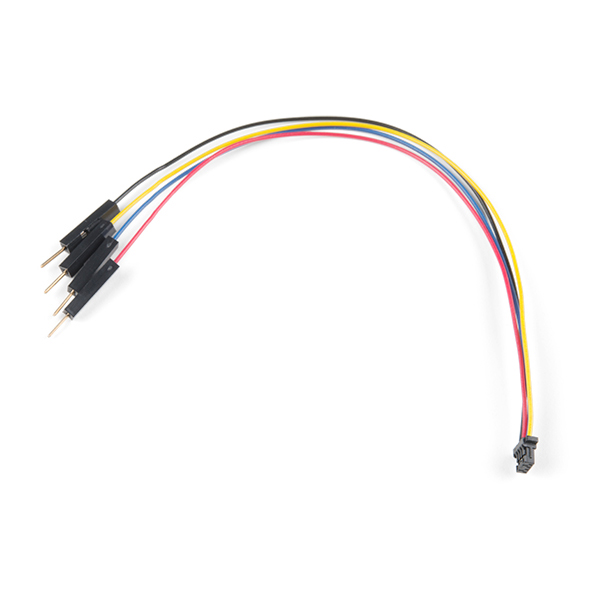
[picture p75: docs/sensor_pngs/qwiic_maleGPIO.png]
Qwiic to male GPIO wire
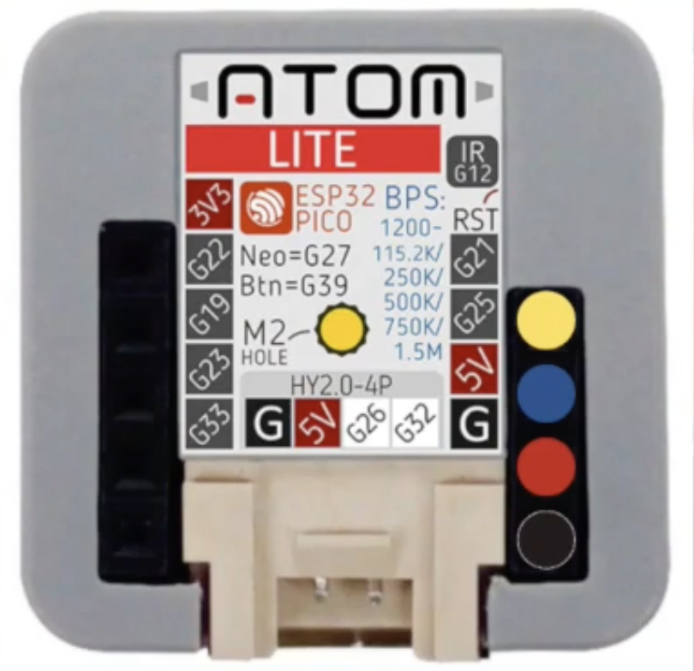
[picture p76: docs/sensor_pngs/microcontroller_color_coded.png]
Microcontroller wiring
|Qwiic Multiport to Microcontroller|Qwiic MultiPort|qwiic to male GPIO wire|Microcontroller|To integrate Qwiic, attach a GPIO to qwiic jumper on ground, 5v, pin 21, and pin 25 of the microcontroller. That is yellow, blue, red, black from top to bottom on the right.|
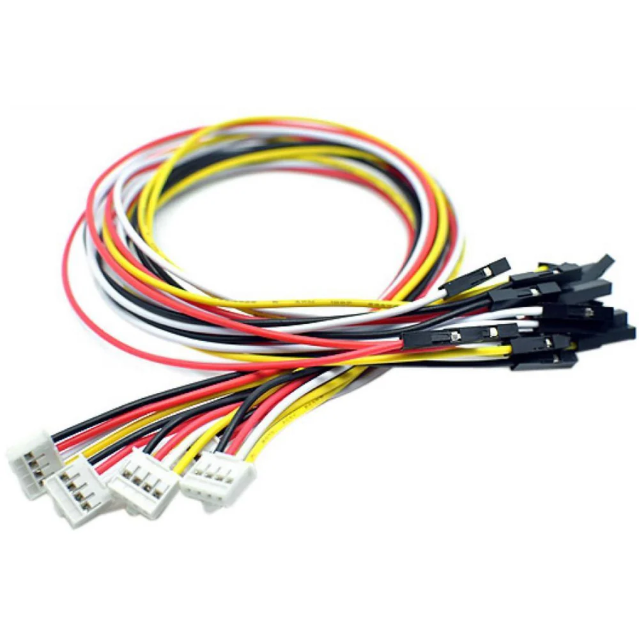
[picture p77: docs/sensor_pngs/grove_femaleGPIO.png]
Grove to female GPIO wire
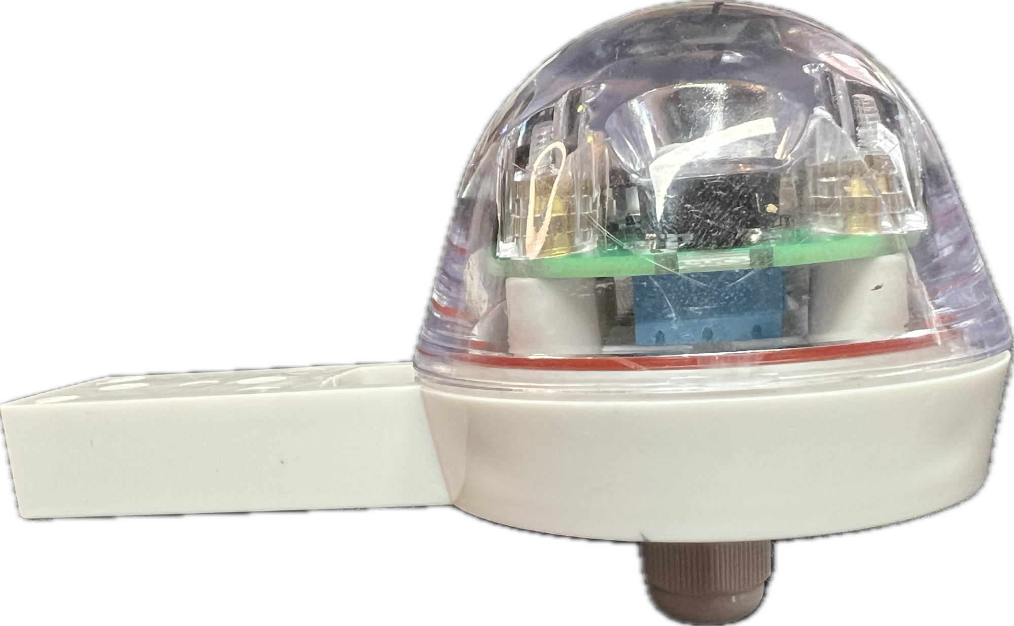
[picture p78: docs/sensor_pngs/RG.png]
Rain Gauge
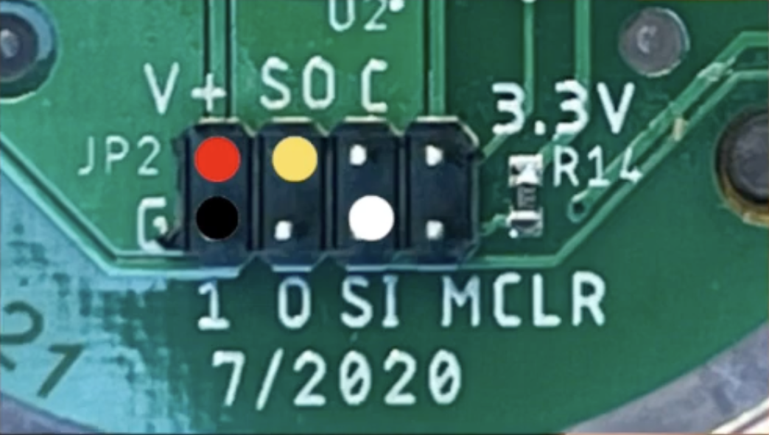
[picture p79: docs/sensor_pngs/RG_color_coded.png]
Rain Gauge Wiring
|Microcontroller to Rain Gauge|Microcontroller|grove to female GPIO wire||Unscrew the base from the rain gauge. Connect the female GPIO wires as indicated. Red (5v, top left), Black(ground, bottom left), Yellow (Input, 2nd from top left), White (Output, 3rd from bottom left).|
|Microcontroller to Power|Microcontroller|USB-C to any power source|Power Source||

####Wiring Diagram
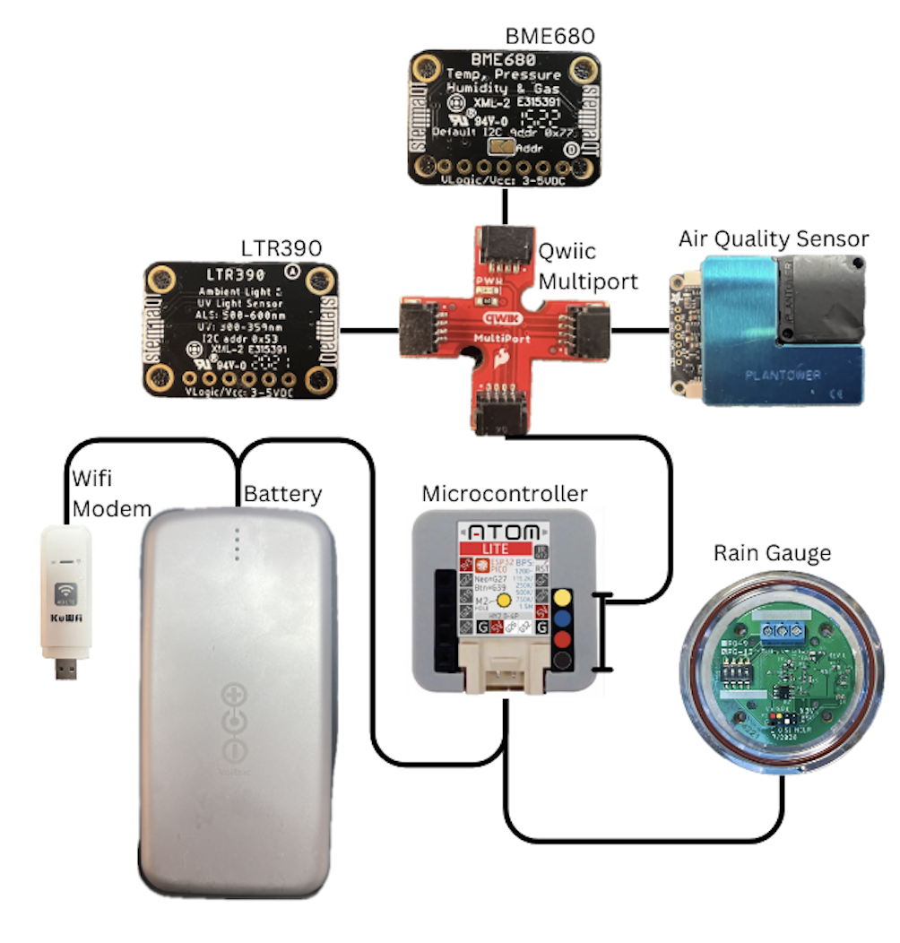
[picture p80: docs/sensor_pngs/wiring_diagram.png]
wiring diagram


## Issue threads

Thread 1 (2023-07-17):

materials list should include optional and "required" components

kmaull-ucar, 2023-07-17:
https://ncar.github.io/openiotwx/getting-started/materials/

For example, there are optional printing items, like:

- PEI sheet for better printing surface

And it isn't clear, which items in the base station should be purchased:
- a base system could be configured with a 10w panel v25 battery
- the base system should include the 4x4x4 (e.g. https://www.homedepot.com/p/4-in-x-4-in-x-4-in-Junction-Box-R5133709/202043437 or https://www.amazon.com/Cantex-5133709U-Junction-Box/dp/B01HCJDHUQ or https://www.gordonelectricsupply.com/p/Cantex-5133709-4X4X4-Pvc-Jct-Box/6043582)

ralter, 2023-08-01:
Added these - good enough? happy to switch off.

Closed 2023-09-07.

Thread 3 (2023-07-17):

software page needs more detail

kmaull-ucar, 2023-07-17:
**1. explain what each piece of software is for in an introductory paragraph:**

There are two primary software packages that you will need to download before you begin.  The first is required to flash the microntrollers, the second is required to load, slice and print the 3d-printed parts.  While we use Arduino for flashing, and Cura for loading and slicing, if you use a different printer, and/or microcontroller combination, you may need to use the appropriate software, which is beyond the scope of this guide.

In the part about Arduino "this is an old release" should be "this is the legacy release" (this is what the community calls it).  The reason is because the SPIFFS file system has not properly been ported to the ESP32 platform at the time of this writing.  At some point 2.x should catch up and we can leave 1.8.x behind.

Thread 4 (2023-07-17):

print page should include wireframe/solid model images of parts

kmaull-ucar, 2023-07-17:
https://ncar.github.io/openiotwx/print/

Can we add images of the parts (screenshots from Cura) or stl->png conversion?

Closed 2023-07-31.

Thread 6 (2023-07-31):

contribution page needs to have link to gh and other ways to contribute

kmaull-ucar, 2023-07-31:
users can contribute in at least these 4 ways:

1. [**general**] complain using the goog form provided (or go to the `-hub` site and make general issues there)
2. [**web**] make suggestions to the website (this repo)
3. [**software**] make code improvements (there are several places to go do this)
4. [**hardware**] make hardware improvements (the `-stl` repo)

Closed 2023-07-31.

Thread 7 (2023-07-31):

contributions page needs a link for umbrella repo

kmaull-ucar, 2023-07-31:
in the first paragragh

``` to this repo(Insert Umbrella Repo) ```

needs to have the correct link

Closed 2023-07-31.

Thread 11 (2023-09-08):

Add the new Air Quality housing (with the sliding slit) to our print doc

daniels303, 2023-09-08:
Add the STL file for the new Air Quality sensor housing (the one with a slit) to the [print doc page](https://ncar.github.io/openiotwx/print/).

Closed 2023-11-07.

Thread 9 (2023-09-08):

Add the "ESP32 Dev" board to the Flashing doc

daniels303, 2023-09-08:
In the [Flashing Microcontrollers doc](https://ncar.github.io/openiotwx/installation/core_install/), add the following URL to the list of Boards Manager list so that "ESP32 Dev" appears via File->Preferences->Additional Boards Manager URLs

https://raw.githubusercontent.com/espressif/arduino-esp32/gh-pages/package_esp32_index.json

Closed 2023-10-02.

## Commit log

2023-06-16 print files and other edits
    [AQ_Housing_Male.step, AQ_Housing_Male.stl, AQ_lid_Female.stl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]
2023-06-20 mostly adding stls in docs sd
    [Cap F-F v2.step, Cap F-F v2.stl, Cap F-M v2.step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]
2023-06-23 print file update
    [UV Cap.stl, UV_Cap_V2.stl]
2023-07-14 added BOM, updated print
    [AQ_Cap.stl, AQ_Housing_Male.step, AQ_Lid_Lock.stl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]
2023-07-24 including base implementation framework
2023-07-27 adding imagery
    [RG15_Housing.step]
2023-07-31 adding images to assembly
2023-11-04 new AQ
    [AQ_Housing_Vented_Male.stl, AQ_Lid_Half_Vented.stl]
2024-08-14 Your descriptive commit message
    [pyvenv.cfg]
2024-08-22 Increasing the robustness of assembly instructions and other organizational updates
2024-09-12 removed myenv
    [pyvenv.cfg]
2024-10-08 Add tutorial links, deployment photos, and updated assembly photos
